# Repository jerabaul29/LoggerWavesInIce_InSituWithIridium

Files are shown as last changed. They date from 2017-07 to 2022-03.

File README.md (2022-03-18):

### NOTE - the content of this repository is kept available for archive, but we have a better instrument design released in 2021, see: https://github.com/jerabaul29/OpenMetBuoy-v2021a .

# Logger waves in ice with solar panel and Iridium communications

This is the repository for the 'waves in ice' instrument developed in this work:

```
An open source, versatile, affordable waves in ice instrument for scientific measurements in the Polar Regions
Jean Rabault, Graig Sutherland, Olav Gundersen, Atle Jensen, Aleksey Marchenko, Øyvind Breivik
```

https://www.sciencedirect.com/science/article/pii/S0165232X19300230

(preprint available here: https://arxiv.org/pdf/1901.02410.pdf ).

## Content of the repository

- **PCB_electronics**: details about the electronics boards.
- **DevelopmentCode**: code for the different components of the loggers.
- **ElectronicsList**: some bookkeeping of which components I need to buy to assemble. May be outdated.
- **SeedOPL**: the Seeed studios standard library. Could be used for putting the components on PCB from factory, not used now.

Quite a lot of cleaning and more detailed readmes is needed. This will happen as time goes and new series of instruments get built. If you have any questions, open an issue and / or feel free to contact me at ```jean.rblt@gmail.com```.

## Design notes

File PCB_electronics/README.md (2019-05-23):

PCB files. The software used for developing this is the Open Source KiCAD.

Most advanced PCB is in **Logger_and_power_v1**.

Production was made through Seeed.

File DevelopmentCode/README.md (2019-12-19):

# DevelopmentCode

Development code for all the modules of the logger, including processing on the Pi.

Each folder contains one component.

The Arduino stuff was developped in Visual Studio Code with the PlatformIO IDE; this may explain for some specificities in the folder structures.

- **ArduinoMega**: the code on the Arduino Mega on the center PCB; effectively, the logger and interface to all other components.

- **PowerControl**: the power controller, ie controlling the solar panel, battery, and wakeup planning.

- **RPI_side**: the stuff on the RPI. An image of the RPi image ready for use is available here: https://folk.uio.no/jeanra/Research/img_0208_Rpi_2Bv11.img .

- The rest is tests, help, etc.

# Old ------------

## To build a logger:

- upload the power controller and put it on the PCB.

Note: check the values in the parameters.h. In particular for production (no debugs or similar, and update the solar panel each 40s, possibility for main
instrument wakeup each 20 minutes):

- DEBUG should be false
- SHOW_LED should be false
- CYCLES\_DEEP\_SLEEP should be 5
- CYCLES\_BEFORE\_MEGA\_WAKEUP should be 30

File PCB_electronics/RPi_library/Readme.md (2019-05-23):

The RPi files are from here:

https://github.com/joeferner/kicad-library/tree/master/libs

The files here are just copies of the content of the repo.

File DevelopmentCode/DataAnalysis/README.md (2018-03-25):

# some code to help looking at the data obtained by the logger

## Setup

- set up a google account for iridium data (if necessary, forward from main account: wheel -> settings -> *filters and blocked addresses* then *forwarding and pop / imap* )
- set up the google account for allowing POP messaging: wheel -> settings -> *forwarding and pop / imap* : enable POP
- set up the google account to accept 'unsafe' applications: wheel -> settings -> *accounts and imports* -> other google account settings -> apps with account access -> allow less secure apps: on
- create a local clone of the repository containing the data (example https://github.uio.no/jeanra/LoggerWaveIceSolarIridiumRaspberry )

## Use of the code

- check if some new data has been received: *python run_interaction_with_gmail.py* . This will download through POP the data received on the gmail account, add it to the local repo, and push. Always use data from the local repo, as data is only obtained once through POP.
- do some plots (NOTE: will need to adapt the parameters of the script, in particular date intervals for plotting): *python run_process_data.py* .

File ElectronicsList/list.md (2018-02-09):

A list of what is needed in terms of electronics:

--------------------------------------------------------------------------------
- v prototype 09 02 2018:

- power manager:
05 -- 1 x ATMega 328P                                       Adafruit
20 -- 2 x IRLB8721                                          Adafruit / Elfa
10 -- 1 x (16 Mhz crystal + 2 capacitors)                   Adafruit
Ol -- 1 x 220 Ohm                                           Elfa
Ol -- 5 x 56 k Ohm                                          Elfa
Ol -- 1 x 39 k Ohm                                          Elfa

- caps
Ol -- 3 x supercap 2.5V 60F                                 Elfa
Ol -- 3 x 30 k Ohm                                          Elfa
Ol -- 1 x cap 40V 1000 micro F                              Elfa
Ol -- 1 x cap 1 micro F                                     Elfa

- step up converter
10 -- 1 x Pololu 5V Step-Up Voltage Regulator U3V50F5       Pololu

- Iridium
3 -- 1 x RockBlock 7                                       RockBlock7
2 + 2 -- 1 x antenna (weather hardened?)                       RockBlock7

- Arduino Mega:
Ol -- 1 x Arduino Mega                                      Elfa
Ol -- 1 x (MAX3323EEPE+ + 4 x 0.1 micro F caps)             Elfa
05 -- 1 x GPS breakout                                      Adafruit
05 -- 1 x GPS antenna                                       Adafruit
05 -- 1 x GPS antenna adapter                               Adafruit
05 -- 1 x SD card reader breakout                           Adafruit
05 -- 1 x SD card                                           Adafruit / Elfa
OK -- 1 x IRF5210                                           Adafruit / Elfa
Ol -- 2 x 46 k Ohm                                          Elfa

- Raspberry Pi:
OK -- 1 x zero or B+ or 2                                   Adafruit / Elfa
-- 1 x micro USB                                         Elfa
-- 1 x (micro USB  -- OR -- USB) to square USB           Elfa

- solar panel:
OK -- 3 x (medium 2W solar panels)                          Adafruit

- to add:
see Olav -- water tight boxe for antenna                          Adafruite / Elfa
see Olav -- pelican cases
OK -- battery cells LiFePO4

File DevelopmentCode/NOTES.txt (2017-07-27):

NOTES

- power control system: give access to all Arduino pins in PCB CAD (using headers).

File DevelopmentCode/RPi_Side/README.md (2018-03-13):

# RPi_side

This folder contains the code to be put on the Raspberry Pi of the logger.

## Present folder structure and files

The following folders and files should be present on the RPi in **/home/pi/Logger/**:

.
├── Code
│   ├── launch_processing_RPI.py
│   ├── RPi_Control.py
│   ├── script_RPi.sh
├── Commands
├── Data
├── filename_list.txt
├── Logs
├── README.md
└── ResultAnalyzis

The following should be added to the sudo crontab (sudo crontab -e):

```
@reboot bash /home/pi/Logger/Code/script_RPi.sh
```

## Setup of the RPi

- Get a copy of Raspbian lite: https://www.raspberrypi.org/downloads/raspbian/
- Use *startup disk creator* to create the SD card with Raspbian
- Make the system able to boot on ssh: add an empty 'ssh' file in the boot partition of the SD card
- Disable internet on main computer
- Connect RPi and computer with ethernet
- Give current to RPi to boot RPi
- Find the IP of the host computer: *hostname -I* Example output: 10.42.0.1
- Find the IP of the RPi: *nmap -sP IP__.\** Example: *nmap -sP 10.42.0.\**
- Connect to the RPi: ssh pi@IP_RPi
- There may be a warning because of SSH fingerprint; follow instructions to ignore
- Default RPi password: raspberry
- Change password on the RPi using the *passwd* command, for example to: user: pi password: 55732gg88j
- Enable internet on main computer to share connection to RPi
- Update RPI: *sudo apt-get update* and *sudo apt-get upgrade*
- Install some base packages: *sudo apt-get install vim* and *sudo apt-get install python-pip* 
- Install pip, and necessary packages: *sudo pip install pyserial*, *sudo pip install printind*, *sudo pip install crcmod* **NOTE**: use *apt-get* instead to not need to compile the heavy packages. example: *sudo apt-get install python-numpy* and *sudo apt-get install python-matplotlib* and *sudo apt-get install python-scipy* .
- Copy the logger files to the RPi and setup the tree structure: go to *example_structure_on_Pi* and *scp -r * pi@IP_Pi:/home/pi/*
- Copy the code to the Code folder: *scp *.py pi@IP_Pi:/home/pi/Logger/Code/* and *scp *.sh pi@IP_Pi:/home/pi/Logger/Code/*
- change the parameters in the logger code: in **launch_processing_debugging.py** use *main_path=/home/pi/Logger* , if necessary make the *debug=True* or *False*. Debug indicates if use the true data or the dummy data for testing the processing code. path is dependent on my laptop vs RPi. verbosity is controlled by the verbose parameter.
- Run tests to check that everything ok.
- Once the system is working and communicating with the logger, reduce boot time following https://folk.uio.no/jeanra/Informatics/GettingStartedRaspberryPi.html : *sudo update-rc.d networking remove* *sudo update-rc.d dhcpcd remove* *sudo systemctl disable dphys-swapfile*
- Prepare the script (*chmod +x script_RPi.sh*) and set up the crontab for automatically starting processing and then shutting off: *sudo crontab -e* and then add the script: *@reboot sh /home/pi/Logger/Code/script_RPi.sh* .
- Do last test with RPi reduced booting time.

## Reminders

Some reminders from https://folk.uio.no/jeanra/Informatics/GettingStartedRaspberryPi.html

### Access to RPi

To be able to talk to the RPi by ssh make sure that:

- Network is available (if necessary crontab) and ssh is openend
- The Pi does not shutoff immediately; for this, may be necessary to plug a dummy
Arduino
- In order to upload code to the RPi, from this folder do: ```scp * pi@10.42.0.214:/home/pi/Logger/Code/.```
- If necessary, see the webpage on my website: https://folk.uio.no/jeanra/Informatics/GettingStartedRaspberryPi.html

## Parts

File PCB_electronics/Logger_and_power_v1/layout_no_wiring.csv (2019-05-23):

Id | Designator | Package | Quantity | Designation | Supplier and ref
1 | C1,C2 | C_Disc_D3_P2.5 | 2 | 20pF
2 | C3 | C_Radial_D8_L11.5_P3.5 | 1 | 1uF
3 | C4,C5,C6,C7 | C_Disc_D3_P2.5 | 4 | 1.0uF
4 | C8 | C_Radial_D8_L13_P3.8 | 1 | 1000uF
5 | D1 | LED-3MM | 1 | LED
6 | IC1 | DIP-28_W7.62mm_LongPads | 1 | ATMEGA328-P
7 | P1 | WireConnection_2.00mmDrill | 1 | SOLAR_PANEL
8 | P2 | WireConnection_2.00mmDrill | 1 | 5V_pololu
9 | P3 | WireConnection_2.00mmDrill | 1 | BATT
10 | P4 | WireConnection_2.00mmDrill | 1 | SUPERCAPS
11 | P5 | Pin_Header_Straight_1x09 | 1 | GPS_breakout_connector
12 | P6 | Pin_Header_Straight_1x08 | 1 | SD_breakout_connector
13 | P7 | Pin_Header_Straight_1x05 | 1 | Iridium_connector
14 | P8 | Pin_Header_Straight_1x04 | 1 | VN100_connector
15 | P9 | Pin_Header_Straight_2x01 | 1 | RPI_connector
16 | P10,P11 | Pin_Header_Straight_1x08 | 2 | CONN_01X08
17 | P12 | Pin_Header_Straight_1x03 | 1 | CONN_01X03
18 | P13,P14,P15 | Pin_Header_Straight_2x01 | 3 | CONN_01X02
19 | R1 | Resistor_Horizontal_RM10mm | 1 | 5.6k
20 | R2 | Resistor_Horizontal_RM10mm | 1 | 3.9k
21 | R3,R5,R6,R7 | Resistor_Horizontal_RM10mm | 4 | 50k
22 | R4 | Resistor_Horizontal_RM10mm | 1 | 220
23 | R8 | Resistor_Horizontal_RM10mm | 1 | 46k
24 | R9 | Resistor_Horizontal_RM10mm | 1 | 32k
25 | U1 | TO-220_Neutral123_Vertical | 1 | IRLB_8721_SOL
26 | U2 | TO-220_Neutral123_Vertical | 1 | IRLS-8721_MEGA
27 | U3 | DIP-16_W7.62mm_LongPads | 1 | MAX232
28 | U4 | TO-220_Neutral123_Vertical | 1 | FQP27P06
29 | XA1 | Arduino_Mega2560_Shield | 1 | Arduino_Mega2560_Shield
30 | Y1 | Crystal_HC49-U_Vertical | 1 | 16MHz
31 | W1 | NetTie-I_Connected | 1 | NET-TIE

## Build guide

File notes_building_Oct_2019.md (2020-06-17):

# build the PCB 'as usual'. Fixes:

- 3.9k -> 39k
- 5.6k -> 56k
- 1.0 uF -> 0.1 uF
- 32k, 46k, 50k -> 47k

# programming procedure

NOTE: all the following is tested on Ubuntu.

## code for the Arduino barebone

- power controller: using commit **b76f6a5** (current master IS BROKEN), upload the code in the **PowerControl** folder on the barebone Arduino (for example, using an Arduino Uno to program the chip). Check the **parameters** and that you are ready for deployment, not test. This can be done either by using ```git checkout``` or by using the folder in **DevelopmentCode/PowerController_commitb76f6a5**.

- go back to master in the code

## code for the Arduino Mega logger

- take away the Arduino from logger shield

- Initialize the EEPROM (run **InitializeEEPROM** on the Mega).

- upload the code (from **ArduinoMega**, current master, for example using commit **39c30775849a**). Make sure that you well use the extended buffer compilation flags (see the platformio.ini parameters folder). The sizes of the data and program should read something in this kind:

```
DATA:    [========  ]  81.5% (used 6673 bytes from 8192 bytes)
PROGRAM: [=         ]  10.9% (used 27732 bytes from 253952 bytes)
```

I use the platformio plugin on Visual Studio Code to compile / upload.

## VN100 setup

The VN100 needs to be setup similarly to the waves in ice logger in binary configuration:

https://github.com/jerabaul29/LoggerWavesInIce/tree/master/Logger_GPS_SD_VN_Binary_output

```
---------------------------------------------------------------
The configuration of the VN100 is:

Baud rate      : 57600
Async          : NoOutput
Binary output 1: 
    Async mode    : Serial Port 1
    Rate dividor  : 80
    Common group  : None
    IMU group     : UncompensatedMag
                    UncompensatedAccel
                    UncompensatedGyro
                    Temp
                    Press
    Attitude group: Yaw Pitch Roll
                    DCM
                    MagNed
                    AccelNed
    IMU filtering : 80
 
 This corresponds to the binary header (in HEX):
 fa 14 3e 00 3a 00
 
 The length of the message is (in byte): 123
 
 Note that the post can have in addition an
 end of line marker (in HEX):
 0a 0d
 ---------------------------------------------------------------
 
 ---------------------------------------------------------------
 To examine the content of the SD card on Linux computer,
 use for example xxd:
 
 tail -x FileName | head -y | xxd
 ---------------------------------------------------------------
 
 ---------------------------------------------------------------
 CAUTION: when using VectorNav software, do not forget to:
 - connect to the sensor
 - write to non volatile memory (right click on the sensor in the tree view)
 - disconnect from the sensor
 ---------------------------------------------------------------
 ```

# Raspberry Pi

NOTE: use RPi Pi 2 Model B v1.2, NOT RPi Pi model B+ v1.2.

This is to setup the RPi SD card.

Can either use the code in the DevelopmentCode / RPi_Side and the tips on my website post: https://folk.uio.no/jeanra/Informatics/GettingStartedRaspberryPi.html .

or

Use the Raspberry Pi image (for example, tested and verified with **img_0208_Rpi_2Bv11.img**). Then:

TODO: find the image from the HDD and upload.

- Format SD card (exFAT)

- Find it the name of the SD card: ```sudo fdisk -l```

- Unmount it (for example, if /dev/mmcblk0 is the SD card): ```sudo umount /dev/mmcblk0```

- Copy the right image using dd. Be careful, this is a 'dangerous' command.

1. note: this works:
    ```sudo dd if=/media/jrlab/SAMSUNG/Images_RPi/img_0208_Rpi_2Bv11.img dd of=/dev/mmcblk0 bs=4M```

2. note: seems that this works
    ```sudo dd if=/media/jrlab/SAMSUNG/Images_RPi/img_0208_Rpi_2Bv11.img | pv | sudo dd of=/dev/mmcblk0 bs=4M```

3. note: seems to work and be relatively fast
    ```sudo dd if=/media/jrlab/SAMSUNG/Images_RPi/img_0208_Rpi_2Bv11.img bs=16M | pv | sudo dd of=/dev/mmcblk0 bs=16M```

- If using a larger SD card than the image size (16GB), for example a 32GB card, resize the root partition to full size:

### method 1 for resizing

1. look with gparted at the right device (for example, /dev/mmcblk0).

2. if necessary, unmount partitions.

3. use resize to grow the root partition (for example, /dev/mmcblk0p2)

### method 2 for resizing

From https://raspberrypi.stackexchange.com/questions/499/how-can-i-resize-my-root-partition .

From the command line or a terminal window enter the following

sudo fdisk /dev/mmcblk0

then type p to list the partition table

you should see three partitions. if you look in the last column labeled System you should have

    W95 FAT32
    Linux
    Linux Swap

make a note of the start number for partiton 2, you will need this later. though it will likely still be on the screen (just in case).

next type d to delete a partition.

You will then be prompted for the number of the partition you want to delete. In the case above you want to delete both the Linux and Linux swap partitions.

So type 2

then type d again and then type 3 to delete the swap partition.

Now you can resize the main partition.

type n to create a new partition.

This new partition needs to be a primary partition so type p.

Next enter 2 when prompted for a partition number.

You will now be prompted for the first sector for the new partition. Enter the start number from the earlier step (the Linux partition)

Next you will be prompted for the last sector you can just hit enter to accept the default which will utilize the remaining disk space.

Type w to save the changes you have made.

Next reboot the system with the following command:

sudo reboot

once the system has reboot and you are back at the commandline enter the following command:

sudo resize2fs /dev/mmcblk0p2

Note: this can take a long time (depending on the card size and speed) be patient and let it finish so you do not mess up the file system and have to start from scratch.

Once it is done reboot the system with the following command:

sudo reboot

You can now verify that the system is using the full capacity of the SD Card by entering the following command:

df -h

### For example, working fine with:

```
(VE_P2) jrlab@jrlab-T150s:~$ sudo fdisk /dev/mmcblk0
[sudo] password for jrlab: 

Welcome to fdisk (util-linux 2.27.1).
Changes will remain in memory only, until you decide to write them.
Be careful before using the write command.

Command (m for help): p
Disk /dev/mmcblk0: 29,7 GiB, 31914983424 bytes, 62333952 sectors
Units: sectors of 1 * 512 = 512 bytes
Sector size (logical/physical): 512 bytes / 512 bytes
I/O size (minimum/optimal): 512 bytes / 512 bytes
Disklabel type: dos
Disk identifier: 0x823a85f9

Device         Boot Start      End  Sectors  Size Id Type
/dev/mmcblk0p1       8192    93236    85045 41,5M  c W95 FAT32 (LBA)
/dev/mmcblk0p2      94208 31116287 31022080 14,8G 83 Linux

Command (m for help): 

Command (m for help): d
Partition number (1,2, default 2): 2

Partition 2 has been deleted.

Command (m for help): n
Partition type
   p   primary (1 primary, 0 extended, 3 free)
   e   extended (container for logical partitions)
Select (default p): p
Partition number (2-4, default 2): 2
First sector (2048-62333951, default 2048): 94208
Last sector, +sectors or +size{K,M,G,T,P} (94208-62333951, default 62333951): 

Created a new partition 2 of type 'Linux' and of size 29,7 GiB.

Command (m for help): w
The partition table has been altered.
Calling ioctl() to re-read partition table.
Syncing disks.

(VE_P2) jrlab@jrlab-T150s:~$ sudo e2fsck -f /dev/mmcblk0p2
e2fsck 1.42.13 (17-May-2015)
Pass 1: Checking inodes, blocks, and sizes
Pass 2: Checking directory structure
Pass 3: Checking directory connectivity
Pass 4: Checking reference counts
Pass 5: Checking group summary information
rootfs: 55411/940576 files (0.2% non-contiguous), 447272/3877760 blocks
(VE_P2) jrlab@jrlab-T150s:~$ sudo resize2fs /dev/mmcblk0p2
resize2fs 1.42.13 (17-May-2015)
Resizing the filesystem on /dev/mmcblk0p2 to 7779968 (4k) blocks.
The filesystem on /dev/mmcblk0p2 is now 7779968 (4k) blocks long.

```

# Buying Iridium credits

- Go to https://rockblock.rock7.com

- Buy the amount of credits and line rental you want.

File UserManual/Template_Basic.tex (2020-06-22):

\documentclass[pdftex,a4paper,12pt,twocolumn,fleqn,captions=tableheading]{scrartcl}

\usepackage[british]{babel}
\usepackage[utf8]{inputenc}
\usepackage[T1]{fontenc}
\usepackage{graphicx}
\usepackage{booktabs}
\usepackage{caption}
\usepackage{subcaption}
\usepackage{lmodern}
\usepackage{microtype}
\usepackage{textcomp}
\usepackage{amssymb}
\usepackage{epstopdf}
\usepackage{capt-of}
\usepackage{amsmath}
\usepackage{float}
\usepackage{xfrac}
\usepackage{dblfloatfix}
\usepackage{url}
\usepackage[squaren,Gray]{SIunits}
\usepackage{commath}
\usepackage{listings}
% \usepackage{siunitx}

\addtokomafont{caption}{\small}
\setkomafont{captionlabel}{\sffamily\bfseries}

\usepackage[nottoc]{tocbibind}

% page layout
\usepackage[a4paper,onecolumn]{geometry}
\geometry{hmargin=60pt,top=60pt,bottom=80pt}
% \geometry{onecolumn,columnsep=20pt}
\geometry{head=10pt,headsep=20pt,foot=35pt}

% header and footer
\usepackage{fancyhdr}
\setlength{\headheight}{15pt}
\pagestyle{fancy}
%\fancyheadoffset{9pt}
%\fancyfootoffset{9pt}
\lhead{}	\chead{User manual IMU instruments with Iridium communications}	\rhead{}
\lfoot{}	\cfoot{J. Rabault \\ \thepage}	\rfoot{}
%\renewcommand{\headrulewidth}{0,1 mm}
\renewcommand{\footrulewidth}{\headrulewidth}

\begin{document}
% top matter
\title{Using the waves in ice IMU instruments with Iridium communications}
\author{J. Rabault
  }
\date{\today}

\maketitle

This is a short user manual for the IMU waves in ice instruments with Iridium communications. In all the following, I describe how the instruments are set up after assembly at UiO, but it should be roughly the same also if they are built in-house by another group. For more details about the instrument, see the detailed paper (Rabault et. al., Cold Region Science and Technology (2020), "An Open Source, Versatile, Affordable Waves in Ice Instrument for Remote Sensing in the Polar Regions"), available as a preprint at: ~\\

\url{https://www.researchgate.net/publication/330241626_An_Open_Source_Versatile_Affordable_Waves_in_Ice_Instrument_for_Remote_Sensing_in_the_Polar_Regions}.

\section{Introduction}

The instrument has a few main components:

\begin{itemize}
  \item Master PCB, including voltage regulator, SD card, GPS connected to its antenna, and some various small components, which are set up on top of an Arduino Mega.
  \item Iridium moden connected to its antenna.
  \item Raspberry Pi microcomputer.
  \item Solar panel and battery.
  \item Inertial Motion Unit (IMU, possibly hidden at the bottom of the box depending on the assembly).
\end{itemize}

All the components are visible on the figures \ref{FromOutside} and \ref{FromInside}.

  \begin{figure}
  \begin{center}
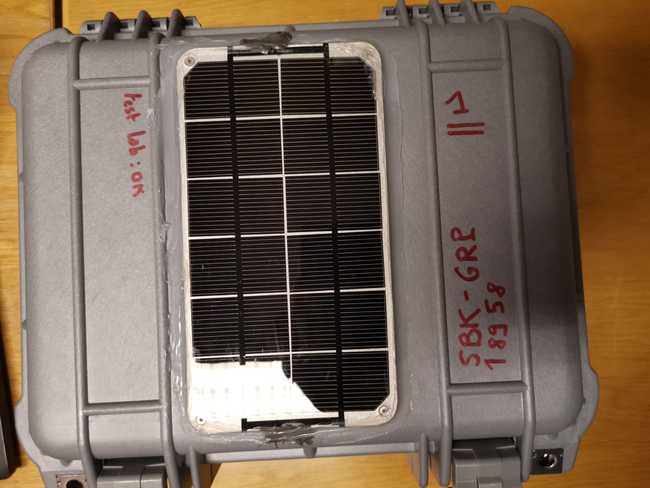
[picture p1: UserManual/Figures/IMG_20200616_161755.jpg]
  
  \caption{\label{FromOutside} The instrument seen from the top, with solar panel, and a written copy of the Iridium modem reference number (here, SBK-GRP 18958). In addition, each instrument in a production series is given a number, here this is instrument number 1.}
  \end{center}
  \end{figure}

  \begin{figure}
  \begin{center}
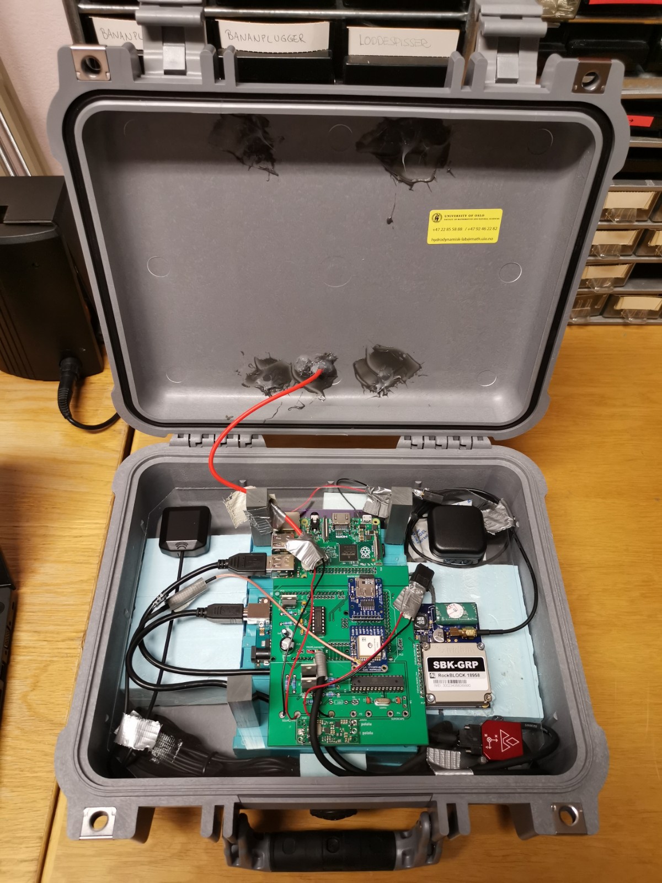
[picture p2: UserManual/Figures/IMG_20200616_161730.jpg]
  
  \caption{\label{FromInside} The instrument seen inside. The different components are clearly visible: IMU (red component at the lower right), GPS antenna (upper left), Iridium antenna (upper right), main PCB on top of an Arduino Mega including SD card reader, GPS module, and small electronics, Iridium model (right), RaspberryPi microcontroller (top), USB cable linking Raspberry Pi and Arduino Mega, single cell battery at the bottom.}
  \end{center}
  \end{figure}

\section{Use}

Any instrument shipped has been fully tested at UiO and should work "out of the box". Instruments being shipped are powered off, and the only step necessary before use is to switch on the instruments (see following). In addition, you need to notify me (address: jean.rblt@gmail.com) before deployment so that I can start Iridium subscriptions for data transmission. If you want to receive a forwarding of the iridium data, send an additional email to the same address. ~\\

To deploy:

\begin{itemize}
  \item Open the instrument. Remember that electronics are very sensitive to static electricity discharges / sparks, so try to touch the PCBs / electronics as little as possible, and try to "discharge yourself" by touching a large metallic mass before opening the instrument. Try to only open the instrument either inside a vehicle, or outside when the conditions are good, so that no snow / water is introduced. Some desiccant bags are hidden at the bottom of the instrument, so it should be fairly resistant to a bit of humidity.
  \item Take a short visual inspection to make sure that the instrument was not damaged during transport: check visually that all cables are in place, and nothing looks broken (SD card inserted, USB cable in place, GPS antenna cable in place).
  \item Find the main power connectors. These should be the only 2 loose connectors present in the box. They may be taped inside the box to make sure that they do not "move around" during transport.
  \item Connect the 2 main power connectors. Make sure that you engage them fully all the way.
  \item At this stage, the GPS LED should start blinking. Depending on the number of sleep cycles left, either it will only blink for a few seconds before turning off (which means that the instrument goes into sleep mode until it should perform a measurement, this is normal), or it will continue blinking, and the SD card reader will start blinking too, in which case a measurement is starting (this is also normal behavior). If nothing blinks, you may consider the "troubleshooting" section. Note that the blinking may be quite low intensity and hard to see, especially outdoors.
  \item At this stage, the instrument is ready: close it and put it on the ice. Make sure that you do not pinch any cables when closing the top lid.
\end{itemize}

  \begin{figure}
  \begin{center}
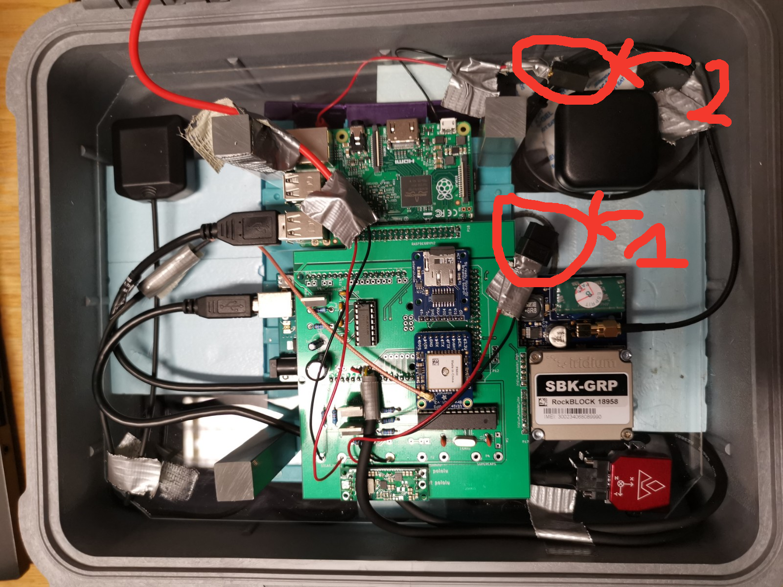
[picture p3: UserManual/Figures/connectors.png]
  
  \caption{\label{Connector} The main power connectors are highlighted in red. Connect them fully and securely, and the instrument will start. Depending on the exact instrument, either the connector shown, or a slightly different connector model, may be used. Feel free to rip off the tape holding the connectors, this is only used to secure everything during transport. The connectors can only be inserted in the right polarisation direction.}
  \end{center}
  \end{figure}

Once this is done, the instrument will periodically transmit through Iridium its position and the wave information. The typical wake-up cycle is: 2.5 hours sleep, 0.5 hours logging, and sending of a message. ~\\

A few points about the instruments deployment:

\begin{itemize}
  \item Place the instrument directly on the ice. If there is a small layer of snow (up to half the height of the box), take away the snow, and put the instrument directly on the ice. Feel free to pack a bit of snow on all 4 sides of the instrument, to stabilize it, without covering it.
  \item The antenna immediately under the lid need a good vision of the sky in order to perform well, so it is important to try to deploy the instrument in a place where it is not too likely to get buried under snow.
  \item The box is water-proof and has buoyancy, however it does not float very well, especially without the addition of an external floater.
\end{itemize}

Try to not start / stop the instruments: just let them on for the full duration of the deployment if no problem is encountered. Do not try to disconnect any cables / remove SD cards or other. All relevant data are transmitted through Iridium anyways. If necessary, to stop the instruments:

\begin{itemize}
  \item Cover the solar panel with a dark, mate, opaque cover, and keep it covered the whole time of the procedure. If not, the solar panel will continue providing enough energy to keep the instrument on.
  \item Disconnect the main power connector. Secure both ends with a bit of tape.
  \item To make sure that all capacitors are emptied, and that all electronics is shut off rather than in compromised browned-out mode, use the provided cable to short the 2 "supercaps" pads, as visible in Fig. \ref{shorting}. Make sure that you perform the shorting AFTER the main power connector has been disconnected, otherwise, you are attempting to short the battery.
\end{itemize}

  \begin{figure}
  \begin{center}
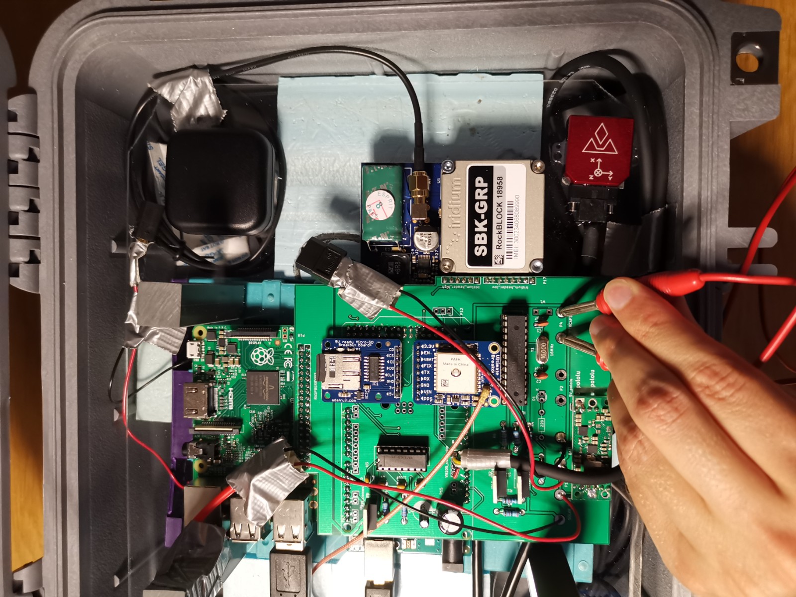
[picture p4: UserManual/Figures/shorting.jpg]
  
  \caption{\label{shorting} shorting of the "supercaps" pins using the provided cable, in order to empty all capacitors and make sure that the electronics is not let in a browned-out state.}
  \end{center}
  \end{figure}

\section{Extraction of raw data}

\textbf{Warning: make sure to be very careful when extracting / inserting SD cards on the main PCB}.

Data of interest (i.e., GPS position, significant wave height, peak period, binned spectra) are transmitted through Iridium. However, the Iridium data do not include the full raw signal.

In order to extract the raw wave data:

\begin{itemize}
  \item Extract the SD card visible on the main PCB. This is a press in / press out mechanism: press and release to eject.
  \item Copy all files on the SD card back to your computer. Do not change anything to the formatting of the SD card or the files contained.
  \item Insert back the SD cad: press and release to insert.
\end{itemize}

I would advise to perform this operation when the logger is sleeping and not active (i.e., no blinking LEDs on the SD and GPS shields), and to not switch on / off the logger for performing this operation. It should take only a few seconds to copy the data, and the probability that the logger wakes up then is quite little. \\~\\

If you perform data extraction from several instruments, \textbf{make sure that each instrument gets back its initial SD card}, i.e. \textbf{do not permutate SD cards between instruments}.

\section{Troubleshooting}

The design has been tested and operated without problems in several campaigns, both in the Arctic and the Antarctic.

The main possible sources of troubles include: 1) the instruments being covered by snow 2) the instruments being destroyed by polar bears 3) the instruments falling in the water / being crushed following ice breakup. If possible, try to mitigate these hazards by choosing a relevant deployment location. These are conflicting trade-offs (for example, for polar bear resistance we chose to design the instruments to have a low profile and no mast, while this also means that the instruments are more likely to get covered by snow).

The instruments should have enough power through the solar panel to sustain continuous operation with around 8 to 10 hours of sun per day. The batteries included should allow operation without any solar input for at least 1 to 2 months depending on the frequency of data transmission.

The only issue encountered so far in deployments was failure to start up due to browned-out state of the electronics. This can happen if the instruments are switched off but not shorted, and / or (note: uncertain) if the instruments are let in the sun before turning on, in which case they may be started by the solar panel alone even without power from the battery.

To reset the instrument and start them in this case, 1) disconnect the main connector, 2) cover the solar panel with something opaque, 3) short the supercaps pads with the provided cable, 4) start the instruments by connecting the main connector.

If other issues occur, or you encounter any problem using or deploying the instruments: take contact with Jean Rabault: jean.rblt@gmail.com.

\end{document}

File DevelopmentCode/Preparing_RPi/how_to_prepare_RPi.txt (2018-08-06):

- possibility 1: if there is already the right iso image for the kind of RPi that is being used:

-- insert SD card
-- re-format
-- find it:
    sudo fdisk -l
-- unmount it (for example, if /dev/mmcblk0 is the SD card):
    sudo umount /dev/mmcblk0
-- copy the right image
note: this works:
    sudo dd if=/media/jrlab/SAMSUNG/Images_RPi/img_0208_Rpi_2Bv11.img dd of=/dev/mmcblk0 bs=4M
note: seems that this works
    sudo dd if=/media/jrlab/SAMSUNG/Images_RPi/img_0208_Rpi_2Bv11.img | pv | sudo dd of=/dev/mmcblk0 bs=4M
note: seems to work and be relatively fast
    sudo dd if=/media/jrlab/SAMSUNG/Images_RPi/img_0208_Rpi_2Bv11.img bs=16M | pv | sudo dd of=/dev/mmcblk0 bs=16M
    
--------------------------------------------------------------------------------
- possibility 2: if no right image for the kind of RPi yet:

-- format SD card
-- Download Raspbian version lite
-- create a SD bootable card using startup disk creator
-- use the RPi with a screen and english keyboard etc to do the setup
-- change password
-- sudo apt-get update
-- sudo apt-get upgrade

-- sudo apt-get install vim
-- sudo apt-get install python-pip

// NOTE: DO NOT use pip, too slow:

// -- sudo pip --no-cache-dir install numpy printind scipy matplotlib binascii fnmatch crcmod pyserial

use sudo:

sudo apt-get install python-numpy python-scipy python-matplotlib
sudo pip --no-cache-dir install printind crcmod pyserial

-- set the crontab:
    crontab -e
and then add:
    @reboot sh /home/pi/Logger/Code/script_RPi.sh
(note: located at rootfs/var/spool/cron/crontabs)

once seems to work:

apply the booting time optimization (suppress output, suppress network, etc)
that are described here:

https://folk.uio.no/jeanra/Informatics/GettingStartedRaspberryPi.html

NOTE: on the RPI 1 B, seems need a reboot to see the Arduino

--------------------------------------------------------------------------------
change password
azerty5+@RPi)

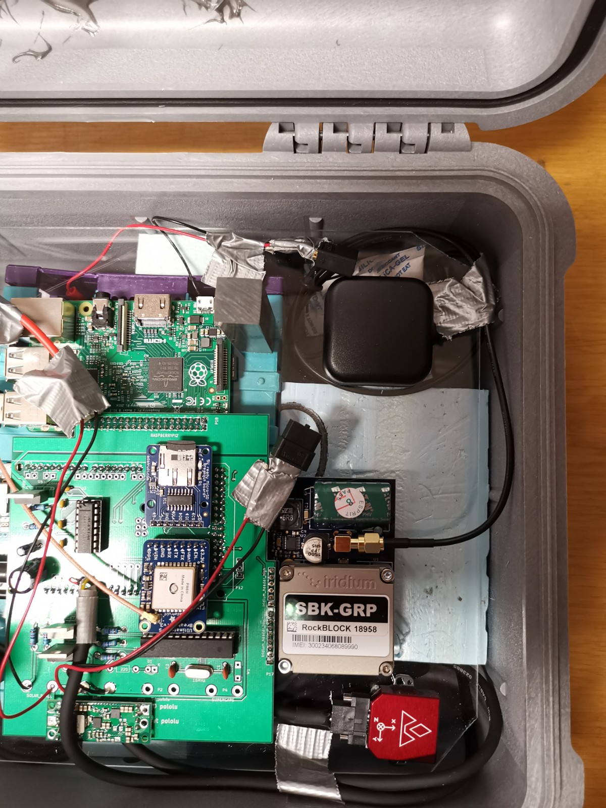
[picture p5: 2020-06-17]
UserManual/Figures/IMG_20200616_161638.jpg

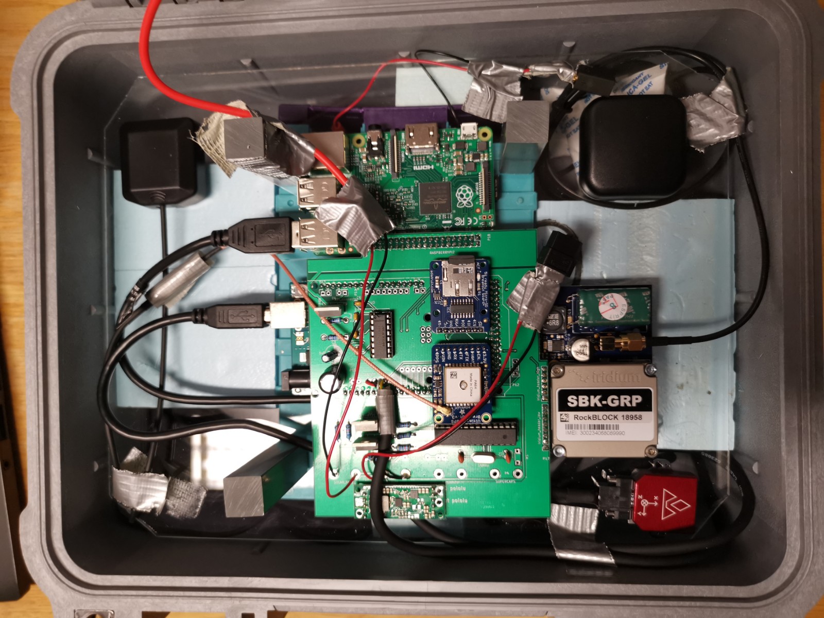
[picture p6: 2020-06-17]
UserManual/Figures/IMG_20200616_161747.jpg

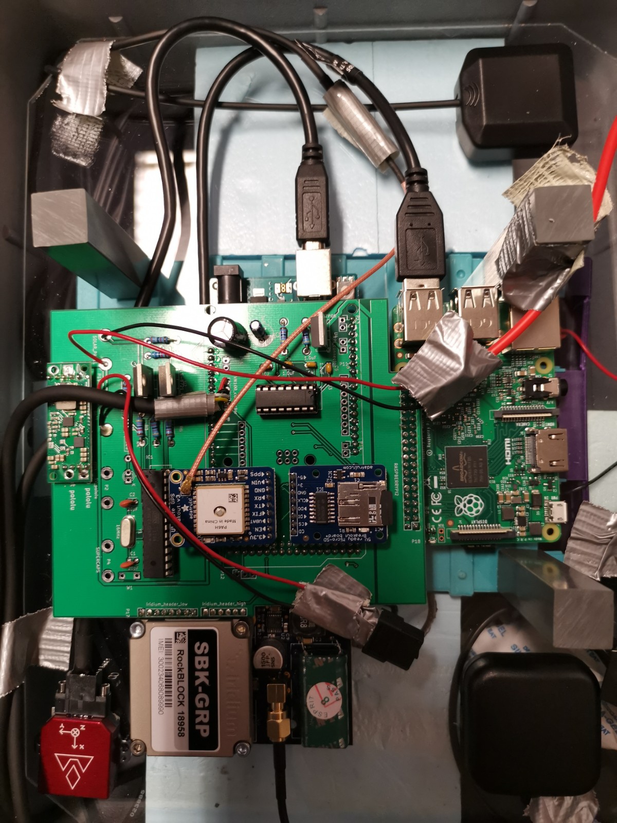
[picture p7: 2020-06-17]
UserManual/Figures/IMG_20200616_161645.jpg

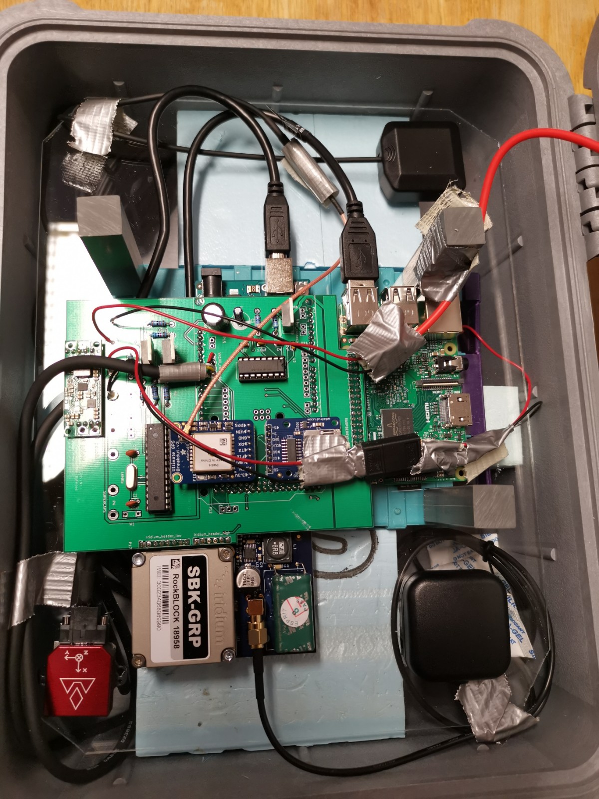
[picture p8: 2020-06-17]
UserManual/Figures/IMG_20200616_161555.jpg

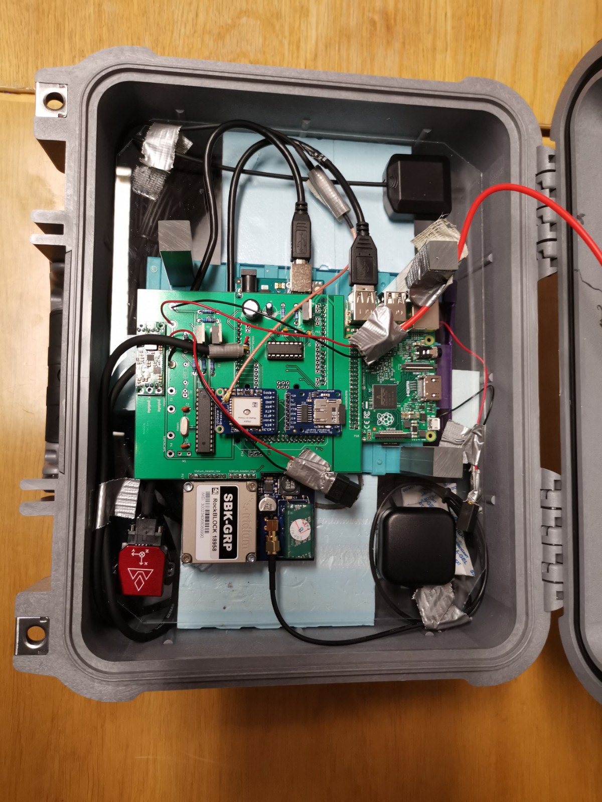
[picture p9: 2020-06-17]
UserManual/Figures/IMG_20200616_161649.jpg

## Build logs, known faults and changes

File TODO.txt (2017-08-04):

- add a 'finished gracefully' stamp in the RaspberryPi folder structure
- try with the other Pi models (less power consumption)
- processing on the Pi
- sending back information from the Pi

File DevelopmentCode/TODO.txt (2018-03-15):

- Electronics CAD:
Do the electronics drawings

- RPi side:
processing code
sending by Iridium

- Arduino side:
send the RPi data through Iridium
timeout on RPi processing to avoid complete hanging

- Power controller: go through code and make a website post

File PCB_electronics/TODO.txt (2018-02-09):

- see if can change to 3.3V everywhere to save power; in worst case, 3.3V / 5V mix
- add capacitors to the board (at least, solder points)
- add the Mega to the board (barebone Mega + include USB FTDI chip)
- add the power regulators to the board (need to buy from TI and deliver to seeed)

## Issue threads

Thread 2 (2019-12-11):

stop charging when full battery

jerabaul29, 2019-12-11:
@jvoermans I would think that these lines:

https://github.com/jerabaul29/LoggerWavesInIce_InSituWithIridium_private/blob/a2df4c4adb81192624e53e88bad405452b68f7e6/DevelopmentCode/PowerControl/solar_controller.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

should ensure that the solar panel does not overcharge the battery. If the voltage is over the max battery level set here:

https://github.com/jerabaul29/LoggerWavesInIce_InSituWithIridium_private/blob/a2df4c4adb81192624e53e88bad405452b68f7e6/DevelopmentCode/PowerControl/parameters.h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

then something very strange is happening.

I see for possibilities:

- 1 a bug in software somewhere.

- 2 a bug in hardware somewhere.

- 3 an overcharged battery before deployment: is it possible that the battery was wrongly charged / overcharged before being put inside the instrument? In this case, I would expect the voltage to be far too high 'since the beginning' of deployment, and it to fall progressively until the max voltage (3.6V), at which point it may either stay constant (if solar panel is strong enough to keep the battery full), or slowly decrease (if solar panel is not strong enough to keep fully charged).

I would be interested to hear if you can check if scenario 3 is corresponding to your results. If so, then it is not the problem of the logger, but how the battery was charged before deployment. If the battery starts at 3.6V, and only progressively while being deployed gets higher, then this indicates scenario 1 or 2 and I need to debug.

jerabaul29, 2020-08-20:
@jvoermans I have several instruments being deployed in the Arctic now, and the batteries are continuously close to fully charged but without overcharging. So it looks like the on / off switching of the solar panel works fine with these instruments....

There may be one explanation for this: are you using the exact same model of MOSFET in your instruments, or did you choose another model? There are many variations around these MOSFETs, and they have subtle differences. If you confirm that you went for another MOSFET model, if may be the explanation.

jvoermans, 2020-08-20:
I don't think the batteries were overcharged. The charger I supplied with the batteries should have overcharge protection.

I looked up the MOSFETs in my receipts, I got the following:
https://au.rs-online.com/web/p/mosfets/7259322/
https://au.rs-online.com/web/p/mosfets/6715064/

jerabaul29, 2020-08-20:
No worries :) . Yes, it looks like it was probably happening during deployment.

Mmh, ok, this looks like exactly the same components I used. Strange.

jvoermans, 2020-11-03:
@jerabaul29 As a follow-up on the above. I think there might be a bug in the code somewhere regarding battery reading.

Today, I just tested the 'added temperature sensor' sketch on an old logger. Battery is at 3.29V, first message said 4.60V, two hours later 4.59V and half hour after 2.98V.

Also, one of the two currently deployed in Antarctica has similar issue regarding battery voltage. It was around 2.5V whole time and still working. They brought it back to the station but battery was fully charged according to the station's electrician (3.5V). Deployed again and stays around 2.5V still working. Any ideas what to test?

jerabaul29, 2020-11-03:
Ok, many thanks for the update! This is strange, as I have never observed the problem myself with my instrument. Wonder if we use a different component somewhere without being aware about it. Or if we are operating in different regimes (maybe this bug appears only when the batteries are completely full and saturate, and this is not something I have observed myself). But then we know that we should just "safely ignore this information".

So it looks like an intermittent hardware / software issue. These can be really quite hard to debug, specially when I myself cannot reproduce the issue... I think it is best to just ignore this problem. Anyways we know the instruments work correctly in reality, which is great, and the most important. This will get better the day I do a full re-design of the instruments (trying to get a project about this, I will keep you posted and invite you to join the application if I am allowed to proceed by my boss :) ).

Closed 2021-11-06.

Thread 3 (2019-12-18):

Power Control

jvoermans, 2019-12-18:
Hi Jean,

Could you tell me how to upload the PowerControl code to the ATMega328P?
Do I just fix it to a Arduino Uno and upload?

Joey

jerabaul29, 2019-12-18:
Hi Joey,

Yes, exactly. The only things you need to be careful about is 1) do not discharge static electricity on the chip (ie touch metal before), 2) be careful to not bend the legs of the chip, 3) insert the chip in the right direction (i.e. check the position of the small circular mark).

Let me know if you have any problems.

Btw, is your instrument still working in the Antarctic? :)

jvoermans, 2019-12-18:
Ok, I did the following:

I directly put the ATMega328 on the Arduino Uno, uploaded the sketch. I put it on one of the spare loggers, but when connecting to power, it just keeps turning on every time I connect it, so I'm doing something wrong.

Should I do something like they do here?:
https://www.instructables.com/id/Build-your-own-Arduino-Bare-Bone-System/

FYI: the ship was still around the loggers, so they simply disconnected and reconnected the battery and it is transmitting again. The ice on which they are deployed is however protected from the Southern ocean by a second strip of ice, so there are basically now waves, but if the batteries are kept fully charged, we just have to wait and hope the ice floes don't melt ;)

jerabaul29, 2019-12-18:
Ok. Did you follow the instructions here?

https://github.com/jerabaul29/LoggerWavesInIce_InSituWithIridium/blob/master/notes_building_Oct_2019.md

"
code for the Arduino barebone
power controller: using commit b76f6a5 (current master IS BROKEN), upload the code in the PowerControl folder on the barebone Arduino (for example, using an Arduino Uno to program the chip). Check the parameters and that you are ready for deployment, not test.

go back to master in the code
"

Yes, this is the right technique. You can just use the Arduino IDE to compile, or platformio.

Ok. Do you mean there are 1 or 2 loggers active now? Is the logger that had a problem working again? Or still only 1 working?

jerabaul29, 2019-12-18:
So:

got checkout b76f6a5

Then upload

Then

git checkout master

You can check the status of the git tracking by 'gut status'. If you are confused I can create a separate folder with the code, may be easier to find, do it adap I have internet access to my computer.

jerabaul29, 2019-12-19:
@jvoermans if you are a bit less familiar with git commands you can just use the power controller code here:

https://github.com/jerabaul29/LoggerWavesInIce_InSituWithIridium/tree/master/DevelopmentCode/PowerControl_commitb76f6a5

Can you confirm to me that it works?

jvoermans, 2019-12-19:
Yes that worked! Thanks. That is one software problem down!

And yes, now both loggers are active again in the Antarctic! Not sure what the problem was, if reconnecting the battery solved it, that means that it is probably a hardware thing.

jerabaul29, 2019-12-19:
Mmmh, very strange, should not be able to happen. Maybe some bad contact of some sort between the battery and the logger that was solved by plugging in and out, or some bad soldering close to the plug that adjusted a bit with playing with the connector. Hope it holds. Good both work again :)

jerabaul29, 2019-12-19:
PS @jvoermans : make sure you adapt the wakeup parameters for wakeup frequency to your needs :)

https://github.com/jerabaul29/LoggerWavesInIce_InSituWithIridium/blob/6cec5acdfae4ed4b094409de874d25b971efb4b8/DevelopmentCode/PowerControl_commitb76f6a5/parameters.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

Closed 2019-12-19.

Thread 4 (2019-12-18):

Arduino PlatformIO

jvoermans, 2019-12-18:
Hi Jean,

I installed VScode with PlatformIO extension on Linux system. I tried to upload the code onto the Arduino, but get some errors. Any suggestions? Below is terminal messages

> Executing task in folder ArduinoMega: platformio run <

Processing megaatmega2560 (platform: atmelavr; board: megaatmega2560; framework: arduino)
--------------------------------------------------------------------------------------------------------------------------------------------------------------------------------------------
Verbose mode can be enabled via `-v, --verbose` option
CONFIGURATION: https://docs.platformio.org/page/boards/atmelavr/megaatmega2560.html
PLATFORM: Atmel AVR 2.0.0 > Arduino Mega or Mega 2560 ATmega2560 (Mega 2560)
HARDWARE: ATMEGA2560 16MHz, 8KB RAM, 248KB Flash
PACKAGES: toolchain-atmelavr 1.50400.190710 (5.4.0), framework-arduino-avr 5.0.0
Converting src.ino
LDF: Library Dependency Finder -> http://bit.ly/configure-pio-ldf
LDF Modes: Finder ~ chain, Compatibility ~ soft
Found 7 compatible libraries
Scanning dependencies...
Dependency Graph
|-- <EEPROM> 2.0
|-- <Adafruit GPS Library> 1.3.0
|   |-- <SPI> 1.0
|   |-- <SoftwareSerial> 1.0
|   |-- <Wire> 1.0
|-- <SoftwareSerial> 1.0
|-- <SPI> 1.0
|-- <Wire> 1.0
|-- <SD>
|   |-- <SPI> 1.0
Building in release mode
Compiling .pio/build/megaatmega2560/src/src.ino.cpp.o
In file included from src/IridiumManager.h:2:0,
                 from /home/joey/Documents/UniMelb/Ice_Logger/ArduinoMega/src/src.ino:44:
src/IridiumSBD.h: In constructor 'IridiumSBD::IridiumSBD(Stream&, int)':
src/IridiumSBD.h:161:18: warning: 'IridiumSBD::lastPowerOnTime' will be initialized after [-Wreorder]
    unsigned long lastPowerOnTime;
                  ^
src/IridiumSBD.h:145:15: warning:   'IridiumSBD::StreamShim IridiumSBD::diag' [-Wreorder]
    StreamShim diag;
               ^
src/IridiumSBD.h:88:4: warning:   when initialized here [-Wreorder]
    IridiumSBD(Stream &str, int sleepPinNo = -1) :
    ^
src/IridiumSBD.h: In constructor 'IridiumSBD::StreamShim::StreamShim(IridiumSBD*, bool)':
src/IridiumSBD.h:123:19: warning: 'IridiumSBD::StreamShim::isbd' will be initialized after [-Wreorder]
       IridiumSBD *isbd;
                   ^
src/IridiumSBD.h:122:12: warning:   'bool IridiumSBD::StreamShim::diags' [-Wreorder]
       bool diags;
            ^
src/IridiumSBD.h:126:7: warning:   when initialized here [-Wreorder]
       StreamShim(IridiumSBD *isbd, bool d) : isbd(isbd), diags(d) {}
       ^
In file included from src/EEPROM_interaction.h:2:0,
                 from src/SDManager.h:3,
                 from src/GPSManager.h:6,
                 from /home/joey/Documents/UniMelb/Ice_Logger/ArduinoMega/src/src.ino:40:
/home/joey/Documents/UniMelb/Ice_Logger/ArduinoMega/src/src.ino: At top level:
/home/joey/.platformio/packages/framework-arduino-avr/libraries/EEPROM/src/EEPROM.h:145:20: warning: 'EEPROM' defined but not used [-Wunused-variable]
 static EEPROMClass EEPROM;
                    ^
Linking .pio/build/megaatmega2560/firmware.elf
lto1: internal compiler error: in lto_output_varpool_node, at lto-cgraph.c:624
Please submit a full bug report,
with preprocessed source if appropriate.
See <http://www.atmel.com> for instructions.
lto-wrapper: fatal error: avr-g++ returned 1 exit status
compilation terminated.
/home/joey/.platformio/packages/toolchain-atmelavr/bin/../lib/gcc/avr/5.4.0/../../../../avr/bin/ld: error: lto-wrapper failed
collect2: error: ld returned 1 exit status
*** [.pio/build/megaatmega2560/firmware.elf] Error 1
================================================================================ [FAILED] Took 0.95 seconds ================================================================================
The terminal process terminated with exit code: 1

Terminal will be reused by tasks, press any key to close it.

jerabaul29, 2019-12-18:
Mmh, strange, I have never seen something like that myself. As you have seen the code compiled nicely on my laptop. Have you tried googling the issue / asking for help online / filling in the bug report?

jerabaul29, 2019-12-18:
(I am traveling at a conference in China, not easy for me to help debug just now. What is the deadline for assembly of your instrument?)

jerabaul29, 2019-12-18:
Which code are you trying to compile? This one right?

https://github.com/jerabaul29/LoggerWavesInIce_InSituWithIridium/tree/master/DevelopmentCode/ArduinoMega/src

You should compile from the src.ino if I remember well.

Worst case if you cannot compile, can you try to use the binary in the .build folder and upload it on the mega without recompiling? You should look for instructions if / how this can be done on platformio (if needed ask for help / open an issue).

jvoermans, 2019-12-18:
Deadline is the end of the month.

I find it a bit confusing. I tried a simple led blink sketch, which uploads to the arduino uno and mega fine through the arduinoIDE. Through platformioIO, it only works for the uno, but not the mega. Then you get the error message:
avrdude: stk500_recv(): programmer is not responding

Seems to be very generic error message, haven't solved that one yet.

I prefer to use platformio as it seems easier to compile, but can I do the same with the arduinoIDE if I restructure the folders and use the extended buffer again?

jerabaul29, 2019-12-18:
Mmh, ok. It is often quite some 'emotions' with assembling hardware on your own for the first time with tight deadlines, but I can do my best to help.

It sounds like there is a very fundamental step in the setup of platformio for the mega that must have a problem.

- are you sure you have installed all necessary packages / dependencies for platformio working with the Arduino Mega?

- are you sure you have selected the right parameters in the code setup so that paltformio us aware it should talk to a mega? There is at least 1 maybe more places in platformio where you have to select Mega from a menu. Also, there may be different kinds of mega, I think if I remember well you have to select mega 2560 or something like that.

jerabaul29, 2019-12-19:
@jvoermans just to illustrate how things look like on my computer (see the options on the lower bar):

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

One more thing: the first time I tried to compile I got an error message for some strange reason, a bit in the same kind of you. But trying to compile one more time, without changing anything, fixed the problem somehow. Can you try to launch compilation a couple of times? You can try first to compile, not upload.

jvoermans, 2019-12-19:
I can open the src.ini file, but do get the following popup message:

C/C++ IntelliSense service does not support .INO files. It might lead to the spurious problems with code completion, linting, and debugging. Please convert .INO sketch into the valid .CPP file.

I already tried compiling multiple times, but get same error message. I think it is not recognizing the board somehow.
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

jerabaul29, 2019-12-19:
- The intellisense error message is not a problem. This just means that the intelligent code completion will not work with .ino files, and that it is recommended to change it into a .cpp file instead.

- Have you tried to troubleshoot with help from the internet? Can this help?

https://github.com/platformio/platform-atmelavr/issues/65

Are you using linux or windows? This looks like windows from your command line output. Many things that are open source do not like windows and break on it. Can you try with a linux computer instead?

- Have you tried to report the bug as suggested? This is related seems to a compiler that was broken. People have god some help on that before:

https://github.com/arduino/arduino-builder/issues/332

https://github.com/arduino/Arduino/issues/7949
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
jvoermans, 2019-12-20:
Nope. Also Linux same issue. A simple sketch through platformio can be uploaded on the mega2560.

I tried now to do all with the ArduinoIDE. I managed all the libraries, but it says it cannot find the 'parameters.h' file, while it is clearly in the folder.

Arduino: 1.8.4 (Linux), Board: "Arduino/Genuino Mega or Mega 2560, ATmega2560 (Mega 2560)"

In file included from sketch/HighSpeedUSBOutputController.cpp:2:0:
/home/joey/Arduino/libraries/DebugMacros_Lib/DebugMacros.h:2:24: fatal error: parameters.h: No such file or directory
 #include "parameters.h"
                        ^
compilation terminated.
exit status 1
Error compiling for board Arduino/Genuino Mega or Mega 2560.

Does this mean I have to add the 'parameters.h' header in the DebugMacros library folder? that sounds a bit weird to me, if I do, I get quite a few other errors

jerabaul29, 2019-12-21:
@jvoermans it should work now:

- I have put a separate folder here that should compile under arduino ide:

https://github.com/jerabaul29/LoggerWavesInIce_InSituWithIridium/tree/master/DevelopmentCode/ArduinoMega_commit6cec5acdf/src

# solution 1: compile locally

- You can compile / upload yourself if you want through the Arduino IDE. For this, you need to update the size of the buffers first. For this, you should find the location of your arduino core, and then go to:

**locations_of_install/arduino-1.8.10/hardware/arduino/avr/cores/arduino**

and there modify the *HardwareSerial.h* to:

```
#if !defined(SERIAL_TX_BUFFER_SIZE)
#if ((RAMEND - RAMSTART) < 1023)
#define SERIAL_TX_BUFFER_SIZE 16
#else
#define SERIAL_TX_BUFFER_SIZE 512
#endif
#endif
#if !defined(SERIAL_RX_BUFFER_SIZE)
#if ((RAMEND - RAMSTART) < 1023)
#define SERIAL_RX_BUFFER_SIZE 16
#else
#define SERIAL_RX_BUFFER_SIZE 512
#endif
#endif
```

(i.e. 2 values of 64 changed to 512). In this case, the compilation should give something like:

```
Sketch uses 28672 bytes (11%) of program storage space. Maximum is 253952 bytes.
Global variables use 6949 bytes (84%) of dynamic memory, leaving 1243 bytes for local variables. Maximum is 8192 bytes.
Low memory available, stability problems may occur.
```

This confirms that a lot of RAM is used because the buffers have been extended.

# solution 2: upload the hex I compiled and put on the repo

- Another solution is to use directly the .hex file I have uploaded on the repo. Not sure though if you should use:

https://github.com/jerabaul29/LoggerWavesInIce_InSituWithIridium/blob/master/DevelopmentCode/ArduinoMega_commit6cec5acdf/src/src.ino.mega.hex

or:

https://github.com/jerabaul29/LoggerWavesInIce_InSituWithIridium/blob/master/DevelopmentCode/ArduinoMega_commit6cec5acdf/src/src.ino.with_bootloader.mega.hex

and to upload it on your arduino mega using XLoader (I have not tried myself before, but should be ok).

How I generated the .hex files:

https://arduino.stackexchange.com/questions/48431/how-to-get-the-firmware-hex-file-from-a-ino-file-containing-the-code

How it should be possible to upload with XLoader:

http://www.hobbytronics.co.uk/arduino-xloader

jvoermans, 2019-12-21:
Thanks Jean for your help. I used the first solution. First upload the initializeEEPROM, then use the extended buffer core to upload the src. Get almost the exact numbers you get:

Sketch uses 28678 bytes (11%) of program storage space. Maximum is 253952 bytes.
Global variables use 6949 bytes (84%) of dynamic memory, leaving 1243 bytes for local variables. Maximum is 8192 bytes.
Low memory available, stability problems may occur.

I'll test tomorrow at uni.

Could you tell me what is different with this folder compared to the other? The compiling goes almost instantly, is it actually compiling or does it bypass and uses info from the hex file?

jerabaul29, 2019-12-21:
Perfect, great that it works!

I think it does do the compilation, no tricks here :) I just fixed a few things in the source code. Keep me informed if it works.

jerabaul29, 2019-12-24:
This seems to work, closing.

Closed 2019-12-24.

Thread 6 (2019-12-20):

building instruments

jerabaul29, 2019-12-20:
@jvoermans how are things going?

- power controller is ok, right?
- how is it going with RPi image?
- how is it going with Mega code upload?

:)

jvoermans, 2019-12-24:
I tried to start the loggers we finished in Oslo, but they act differently. I think it is the battery I used (I connected it to 2x AA batteries). Measuring the voltage across the step-up converter seems alright, but when the logger is supposed to log, the GPS keeps blinking for 1-2 minutes, then the SD card finally started recording, and at the end of the 25 minutes of recording, it started blinking with lower frequency. After 25 min it stopped (as usual) but the RPi never started. I checked the file, the accelerometer data seems fine, and all in the file, but the last part a lot of zeros popup and infrequently it gives accelerometer data. The fact that it starts recording (irrespective of the RPi doing its work), does that mean that the RPi is successfully identified by the arduino, that is, would it start recording when the RPi is not attached?

Do you think the battery is the issue?

When I use the 'logger in ice' (without iridium), and connect to the computer, everything works normal. So I think its the battery. It's Christmas here, so can't get a proper battery right now to test, so have to wait for that unfortunately. If you ever experienced something like the described, let me know.

jvoermans, 2019-12-24:
Also, I used a 1000uF (16V) rather than 1000uF (10V) capacitor and a 1uF (63V) instead of 1uF (50V), (electro guys said it wouldn't matter for the Arduino). Would you agree?

jerabaul29, 2019-12-24:
- The capacitors make no difference at all, agree with your engineers :)

- Yes, I think your batteries are too weak. Can you try 3 X AA in series? The problem is that AA nominal voltage is 1.5V, actually closer to 1.4V, so 2.8V total. In addition when you add voltage drop due to internal resistance you may be down to maybe 2.75 or 2.7 V. In this case, the logger may automatically shut off when a large load (RPi) wakes up, and / or the voltage may drop too low and things start to fail. I think this may also explain for your strange data. Also, those batteries have very little capacity, so they may be quite depleted (and then ever lower voltage) by the time the RPi wakes up. When the RPi is on the intensity draw on the batteries may be up to 1.5 or 2 A, which is a lot for so small cells.

- which RPi model do you use? The same you had to Oslo? Do you see some of the LEDs of the RPi turning on at some point at all?

- Can you use a lab power supply at 3.1V as input to you logger prototype rather than batteries?

jerabaul29, 2019-12-24:
PS: still getting data from Antarctica?

Merry Christmas! :)

jvoermans, 2019-12-24:
Yes, they are still working and still full battery. Still no waves though :p but at this rate they can survive for a long time.

I'll ask if they have bench power supply, how many amps should I use with 3.1V?

Jij ook vrolijk kerstfeest!

jerabaul29, 2019-12-24:
Excellent, so happy with the successful deployment, that really makes me happy 🎉🎉 Hope for sun to keep the batteries happy, no snow falls to not cover the antenna, and some waves some time soon!

You should use a lab supply, put it in 'set voltage' at 3.1V, and put a max intensity at 5A or something like this. I.e. it should be voltage regulated without any intensity limit in practice (high enough to not limit).

jvoermans, 2019-12-30:
Surprisingly, still not working!

I used a bench power supply, 3.3V, max 5A.

This is what happens:
-everything goes normal, after few reconnections of battery, logging occurs rather quickly as it should be, current drawn about 0.2A for 25 min.
-Then for 5-6 minutes, nothing really happens with the RPi, only GPS breakout blinks normally, and the current stays around 0.3A, and every 20 seconds, it increases in 1-3 seconds to 0.5A after which it drops back to 0.3A
-After that, the green light starts burning of the RPi, this takes 2 minutes.
-Then RPi doesn't do anything, only GPS breakout blinks for about 10 seconds and the sequence is over.

One thing, I accidentally mixed up the SD-cards of the RPi's. Is that an issue? I rotated all three SDcards of the RPi to see if anything changes but they all lead to the same result.

Also, accelerometer data files are fine on the SDcard of the breakout. They are not present on the RPi, so they were not transferred to the RPi.

Also, is it normal that the logger can log even without the RPi being attached? This is not the case for the Iridium, if I detach that one, it won't start logging...

jerabaul29, 2019-12-30:
Ok.

This sounds like everything is fine until the RPi and the Mega should talk. Somehow they do not manage to talk to each other, this is when the sequence is aborted.

Are you well connecting the RPi and the Mega with an USB cable? Have you checked that the USB cable is 'good' (can you upload an Arduino sketch through it for example? Some USB cables are 'dummies' that only transfer power, no data).

Yes, it is expected that the loggers work without RPi, bug not without Iridium.

Are you sure you correctly burned the image on the SD card following the instructions? Can you just give power to a RPi through the mini USB and let it boot, and check that both the green and red lights blink then?

Which model of RPi are you using? Is it the same as you used when in Oslo?

Eiserklaus, 2019-12-30:
Hi,

I have no hardware here to test anything (as mentioned I left Labmaker) but my 2 cents: intermittent fails of Raspis are most often power issues. I experienced fails in one of my projects each time the USB wifi tried to send due to insufficient power. So my idea would be to power the Arduino separately (if it is not) and try perhaps a large capacitor in the power supply to bridge peak power consumption. Same considerations may hold true for other power intensive components like the Iridium.
Also removing all useless (power-) LEDs on the Raspi and Arduino may help to some extent.

jerabaul29, 2019-12-30:
Yes, power is always a possible issue. But we know that with steady 3V input this setup should work fine... Wonder if there is another problem: RPi version, SD card preparation, faulty USB cable or other.

jerabaul29, 2019-12-31:
Ok, looks like this does is a power issue encountered when using a lab power supply instead of a battery, strange. Probably the step up converter does not like having an input with any ripples or something like that. Will investigate with pololu. @jvoermans let us know when you have sent the message to them.

jerabaul29, 2020-01-02:
@jvoermans can you confirm this was due to wrong settings of your power supply, and that the new series of instruments you built and programmed works fine? If this is well the case feel free to close.

jvoermans, 2020-01-02:
Haven't been able to test the settings of the power supply yet. Most likely, problem is the power supply, increasing the voltage of the bench power supply to 4.5V led to a steady input voltage of 5.2V on the PCB (both with Arduino active and inactive).

jerabaul29, 2020-01-02:
There should be a way to set the max current of the supply and increase it to a few amps, enough to power at 3.2V. Can you ask your engineers for help? Should do the trick.

jvoermans, 2020-01-02:
I think the max current is standard at 5.2A. When you turn on the supply, it shows briefly the current settings. But I have to double check. I'll get back on this.

jerabaul29, 2020-01-02:
5.2 A should be enough at 3.2V. I would think there is a restriction on it now. May be wrong though.

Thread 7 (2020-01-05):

Iridium transmission

jvoermans, 2020-01-05:
@jerabaul29
is the RPi or the Arduino responsible for the final transmission of data? i.e. if I want to send temperature through Iridium as well, perhaps easiest to do with the GPS data transmission, what files should I start?

Is that in the 'IridiumManager.cpp' file?

jerabaul29, 2020-01-05:
The Arduino is responsible. Yes, it is this file. I let you look at the code to get started. Basically, you need to 1) write the day in the TX buffer of the Iridium 2) ask to send.

Eiserklaus, 2020-01-08:
Hi,

Hi, would this module be of any value for your research:
https://www.taoglas.com/product/edge-locate/

jerabaul29, 2020-01-08:
Hi,

This could be of interest for measuring very low frequency waves, but I think the IMU is a bit better in our case (we manage to measure waves of a few mms, but this has a cm resolution only).

Closed 2021-11-06.

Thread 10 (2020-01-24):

enhancement: I2C power / Mega

jerabaul29, 2020-01-24:
Would be great to have the Power and Mega parts talk through I2C, instead / in addition to the simple wire information.

Closed 2021-11-06.

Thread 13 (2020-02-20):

TODO: add a 'solar power energy dissipation' mechanism

jerabaul29, 2020-02-20:
It is stupid / sad to waste electrical energy produced in excess by the solar panel by simply disconnecting it when the battery is cold. This energy would better be used to simply add a bit of heat inside the pelican case. TODO: add a MOSFET-controlled dissipation resistance on the power management module, so as to be able to switch on dissipation of up to around 5W of electrical power when the battery is full and the solar panel productive.

Closed 2021-11-06.

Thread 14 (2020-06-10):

TODO: add on / off switch

jerabaul29, 2020-06-10:
Add on / off switch:

- off makes sure all caps are emptied to avoid browned-out protection and failure to start
- on makes everything on.

Closed 2021-11-06.

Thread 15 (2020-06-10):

check battery protection

jerabaul29, 2020-06-10:
it is possible that there is a problem with battery protection; check.

Closed 2020-08-20.

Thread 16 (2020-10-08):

ArduinoMega

jvoermans, 2020-10-08:
@jerabaul29 I've been trying to get the code on the ArduinoMega, this time I attempted through VSC again, but there is an error that pops up everytime:
C:\Users\jvoermans\.platformio\lib\Adafruit GPS Library_ID20\src/Adafruit_GPS.h:58:28: fatal error: SoftwareSerial.h: No such file or directory

jerabaul29, 2020-10-08:
You need to put the Software Serial in the lib folder. Just put the whole content of

https://github.com/arduino/ArduinoCore-avr/tree/master/libraries/SoftwareSerial

In lib in the project and let me know if it works.

jvoermans, 2020-10-08:
I added SoftwareSerial folder and the h/cpp files in the lib folder, but still get the same error. See figure attached.

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

jerabaul29, 2020-10-08:
Mmh, strange, are you sure that the whole Software serial is in the lib folder? I.e. do you well have the liv/SoftwareSerial/src and everything there?

# possible fix 1

A possibility is that you may need to change to ```#include "SoftwareSerial.h"``` here:

https://github.com/jerabaul29/LoggerWavesInIce_InSituWithIridium/blob/7bb2ff9ef0ba867dc73101b6fbd4b49d061ea94f/DevelopmentCode/ArduinoMega/src/GPSManager.h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

# possible fix 2

Otherwise, can you follow the advice, and install directly through the platformio software dependency manager as suggested in the output?

# best to "keep it as it was working before"

But you were able to compile this before as you already built some loggers, right? Can you just use the exact same method as what you used and was working before? I set this up a long time ago, I may have been a bit sloppy with the dependencies management, I will try to be more consistent on newer code.

jvoermans, 2020-10-08:
Yes, uploading through the Arduino IDE  you provided works absolutely fine. But I wanted to move to VSC so tried again.

The above didn't work either, however, I added 'lib_ldf_mode = deep' to the platformio.ini file did the trick
https://community.platformio.org/t/build-fails-because-missing-library-include-arduino-framework/14146/2

I end up with a different error now, it looks quite familiar, I think this is where I ended last time with the errors 'ld.exe: error: lto-wrapper failed'. I'll just working from the IDE then for this one

jerabaul29, 2020-10-09:
Ok, sounds good! Yes it works on my Plarformio, not sure why not on yours. I suppose I installed some libraries globally on my machine. I will not do this in the future ,but always put stuff in the lib folder, this way it will be fully reproducible :) .

Ok, good luck!

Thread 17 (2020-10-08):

Extended Buffer

jvoermans, 2020-10-08:
To get back to this topic. I was re-attempting to get the extended buffer working on my work laptop again (Windows 10), and finally figured out why it wasn't working. Apparently, Windows 10 has a hidden Arduino folder in 'AppData'. If you go to File-->Preferences in the Arduino IDE, there is at the bottom a location where the Arduino 'preferences' are stored. Here is another folder with all the boards, cores etc. I'm sure you can change the settings of that somewhere, but changing it in the 'AppData' folder works fine for me. Anyway, not relevant for you on Linux, but perhaps good to document.

I had a question regarding which files you have to change the buffers. Is it just in the HardwareSerial.h, as you stated earlier:
https://github.com/jerabaul29/LoggerWavesInIce/tree/master/ArduinoMegaExtendedSerialBuffers

Or also in the 'USBAPI.h' as stated in another source:
https://www.hobbytronics.co.uk/arduino-serial-buffer-size

jerabaul29, 2020-10-08:
I do not have access to a Windows computer and cannot help debug on Windows platforms.

Do you have access to a Linux computer? That would be the simplest. If not, can you ask Alexander to buy for your lab a Thinkpad T490 or similar, put Ubuntu 20.04 on it, and use it as "the lab's Ubuntu machine"? It is a pain to write code on Linux and make sure it works on Windows...

My post should be a good description of what I did. That was a long time ago though, I do not remember everything.

For this specific project: you had a successful method for uploading the code on the Mega as you built several instruments last year, right? :) Can you continue with this method (the "don t fix it if it s not broken", apologies ^^). This code starts to be quite old, I do not really want to spend to much time supporting it, would prefer to re-develop something much cleaner.

jerabaul29, 2020-10-08:
See this:

https://github.com/jerabaul29/LoggerWavesInIce_InSituWithIridium/issues/4

jvoermans, 2020-10-08:
All good

Closed 2020-10-08.

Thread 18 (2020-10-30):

Add sensors

jvoermans, 2020-10-30:
@jerabaul29 Hi Jean, trying to explain my approach on how to change the sketch to have the first Iridium message include mean temperature from a  sensor. Could you guide me in whether this is ok to do?

(1) measure temperature directly after logging has finished. So some lines to record temperature over, say 2 minutes, comes in between these lines:

https://github.com/jerabaul29/LoggerWavesInIce_InSituWithIridium/blob/7bb2ff9ef0ba867dc73101b6fbd4b49d061ea94f/DevelopmentCode/ArduinoMega_commit6cec5acdf/src/src.in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

(2) Store the mean temperature in a variable, for example: TEMP_AVE

(3) Add lines to the 'message to be send'. Probably copying and editing this:
https://github.com/jerabaul29/LoggerWavesInIce_InSituWithIridium/blob/7bb2ff9ef0ba867dc73101b6fbd4b49d061ea94f/DevelopmentCode/ArduinoMega_commit6cec5acdf/src/Iridiu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
If the temperature is stored under a variable "TEMP_AVE", can I just say:
String TEMP_AVE_string = String{TEMP_AVE};  ?

(4) Add something similar as this in the header file:
https://github.com/jerabaul29/LoggerWavesInIce_InSituWithIridium/blob/7bb2ff9ef0ba867dc73101b6fbd4b49d061ea94f/DevelopmentCode/ArduinoMega_commit6cec5acdf/src/Iridiu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

Am I forgetting something? while this increases the bytes of the message, there is no problem technically I assume?

jerabaul29, 2020-10-30:
Yes, exactly, that should be all what you need to do. A few notes:

- you should develop your code on a new branch, forked from the commit ```39c30775849a```. I created just a branch just now, so you can work directly on it :) https://github.com/jerabaul29/LoggerWavesInIce_InSituWithIridium/tree/feat/add-temp-meas

- remember to regularly reset the watchdog if you have code running some logging for a long amount of time. The command is simple: ```wdt_reset();```

- you will also need to tune a bit the python code for deciphering the iridium messages, but that should be fine.

Yes, there should be plenty of space left on the status message for adding this information.

One more thing: I do not really think that you need to take the average over such a long periods. If the measuring time is 10 ms, maybe it should be enough to average over 100 measurements ie 1 second?

jvoermans, 2020-10-30:
Thanks. You might have explained already, but what is the watchdog exactly?

jerabaul29, 2020-10-30:
It resets and reboots the board if not called regularly. The ```wdt_reset()``` command is what resets it, confirming that the program is running well without hanging.

https://circuits4you.com/2018/01/24/tutorial-on-arduino-watchdog-timer-setup/

jvoermans, 2020-11-03:
Ok I was able to get temperature in the GPS Iridium message. In a separate clone of the repo I did last week.

To work from the branch instead, I cloned the 'feat/add-temp-meas' branch. I added the word 'test' in the readme file of the branch, and tried to push it, but I get a 'unable to access' error. Do I need permission from you I guess to push it?

jerabaul29, 2020-11-03:
That sounds excellent, congratulations!

I think you may need actually to perform a pull request since this is a public repo. See:

https://docs.github.com/en/free-pro-team@latest/github/collaborating-with-issues-and-pull-requests/about-pull-requests

https://docs.github.com/en/free-pro-team@latest/github/collaborating-with-issues-and-pull-requests/creating-a-pull-request

https://yangsu.github.io/pull-request-tutorial/

Basically when there is a public repo, there are not always collaborators as in a private repo, and to make it possible for everybody to participate but for the owner to still have control, there is this pull request system. It works very well :)

Let me know if anything is unclear.

jerabaul29, 2020-11-03:
(note: you may need to create a public fork before you can do a pull request; may be easier to just fork first, then copy paste your changes anew, and then do a pull request).

Closed 2021-11-06.

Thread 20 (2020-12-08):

3.3V pin

jvoermans, 2020-12-08:
@jerabaul29 I think the 3.3V pin is not connected to anything right? So I can use it for 3.3V sensors?

jerabaul29, 2020-12-08:
Mmh, which pin? Arduino Due 3.3V? Yes, it should be a stable and safe 3.3V source. Why? :)

jvoermans, 2020-12-08:
No, the mega 3.3V pin. We solder it but I don't think I see it going anywhere. The temperature sensors of blue robotics each need an I2C level converter for 5V to 3.3V (supply voltage 5V is fine, but logic needs maximum 3.6V), so this problem is for mega only. But the converters of bluerobotics are relatively big and expensive compared to others as they have two easy click sockets which I won't use:
https://bluerobotics.com/store/comm-control-power/tether-interface/level-converter-r1/

Sparkfun has this one:
https://www.sparkfun.com/products/12009

but it needs a reference Voltage of 3.3V.

jerabaul29, 2020-12-09:
Yes, sorry, I was answering too many issues in bulk and had not noticed this was on another repo :)

So basically:

- yes, feel free to use the 3.3V as a powering pin. It is obtained by a low dropout regulator tapping on the 5V rail. It is perfectly fine to use it :)

- I think the sparkfun adapter looks very good. Should work out of the box without problem. Make sure to test it in details :)

Let me know if you have any problems.

Closed 2021-11-06.

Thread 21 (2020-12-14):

Interrupt

jvoermans, 2020-12-14:
@jerabaul29 Is there going to be a conflict somewhere in the software if I use 'attachInterrupt' to measure wind speed?  I'm not an expert on the interrupt function, but it seems it can conflict easily with other processes running on the background...

jerabaul29, 2020-12-15:
Mmh, I do not think it should, as the interrupt will be on the specific pin you attach to. There are many interrupt handlers routines, so that it is possible to have several interrupts defined at the same time. Would be best to test and check of course, but I would guess this should work :) .

Let me know when you test and how. Maybe you can create a separate project for this feature, and I can take care of putting in the main code? :)

Closed 2021-11-06.

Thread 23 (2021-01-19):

using 32GB card image

jerabaul29, 2021-01-19:
@jvoermans let's discuss here how it goes with using the 32GB card image.

jvoermans, 2021-01-20:
initially solved. Will do test today...

jvoermans, 2021-01-20:
You remember when the instrument was deployed in the Antarctic and only GPS messages came through, not the spectra? I first thought the SD card of the RPi was full (which is why I wanted to make sure this time I increased the size). I now actually think the battery is starting to get empty and cannot handle the RPi anymore, draws too much current, and voltage drops to about 3.6V instead of 5.1-5.2V. So, until the RPi is started, everything works fine, but from there on not anymore...

jvoermans, 2021-01-21:
Works!

jvoermans, 2021-01-21:
Am I missing the 'close' button somewhere? Or are you the only one able to do so? ;)

jerabaul29, 2021-01-21:
Mmh no you should be able to close too. See the button left to Comment :) .

Great that it works :) .

jvoermans, 2021-01-22:
That's what I though. I might be crazy...
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

jerabaul29, 2021-01-22:
Really weird. I will close then.

Closed 2021-01-22.

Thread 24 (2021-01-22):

Low memory

jvoermans, 2021-01-22:
@jerabaul29 Is it possible that the low memory (i.e. ~90% of dynamic memory is used and low memory warning is given) is a problem when adding more sensors? The sketch compiles fine, the logger starts, but does not record (i.e., after 6 blinks of the GPS unit, the SD card doesn't start recording).

For example, if I add 3 temperature probes and the sonar, it works. But when I add the pressure sensor, it doesn't. Removing one temperature probe and adding the pressure sensor back and it works again...

jerabaul29, 2021-01-23:
Mmmh, it is possible. I never thought about adding so many sensors... Is it ok to limit just a bit the number of sensors so that things work?

On the instruments V3 that I think of I will use a board with much, much more memory that has become available only very recently. This will solve this kind of problems...

I think you may consider which sensors to put on this Vs the new Due loggers. For example maybe the sonar would be better on the due, recording both distance and full ping profile as I am working on? ... I have some compilation problems at the moment but will look at it this WE.

jvoermans, 2021-01-24:
Ah ok. Yes, I guess pressure sensor can go. It is least important to the experiments. Although Meteorologists are especially interested in that...

I find that 7493 bytes of dynamic memory is more or less the threshold, though it seems to differ a bit. I think I'm short about 10-20 bytes to get all sensors in. Btw, can I change the String below into: String(F("B,\n") ?
That would give me 4 bytes... Or does this mess things up?

For example,:
https://github.com/jerabaul29/LoggerWavesInIce_InSituWithIridium/blob/7bb2ff9ef0ba867dc73101b6fbd4b49d061ea94f/DevelopmentCode/ArduinoMega_commit6cec5acdf/src/VN100M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

jerabaul29, 2021-01-24:
No I do not think you should change that, as this is used by the RPi parsing. I will go through the code quickly now and look for possibilities to reduce memory use. I let you know.

jerabaul29, 2021-01-24:
Ok, a few tips for freeing a bit extra memory. Note that this will change some buffers sizes etc, so you should definitely test before deciding if things work. Are you well compiling from platformio, or from something else?

To get a bit extra available memory:

- Start from the code for the "working" Due code as usual: commit **39c30775849a** .

- The main place with potential for reducing the memory consumption is the serial buffers. As said, it is a bit tricky to reduce, and may have unexpected consequences, so you should double check carefully that things still work after. To reduce a bit the memory consumption, you should modify the ```platformio.ini``` file, at the root of ```LoggerWavesInIce_InSituWithIridium/DevelopmentCode/ArduinoMega/src```. There, the critical values are the ones in:

```
build_flags = -D SERIAL_RX_BUFFER_SIZE=512 -D SERIAL_TX_BUFFER_SIZE=512
```

You could try for example the following values:

- quite tough reduction:  ```build_flags = -D SERIAL_RX_BUFFER_SIZE=400 -D SERIAL_TX_BUFFER_SIZE=400```
- if the previous reduction does not work, can try a less hard reduction: ```build_flags = -D SERIAL_RX_BUFFER_SIZE=450 -D SERIAL_TX_BUFFER_SIZE=450```

Let me know how this goes. I think that the first solution has a good chance to work, and then you should get plenty of RAM back (on the order of slightly under 1KB extra available RAM). If it does not work fine, then the second one may do. If the second one does not work either let me know.

jerabaul29, 2021-01-24:
I just tested the configuration with size ```400```, it should free about 10% of the RAM. I think it *should* work fine, but let me know how tests go.

Closed 2021-11-06.

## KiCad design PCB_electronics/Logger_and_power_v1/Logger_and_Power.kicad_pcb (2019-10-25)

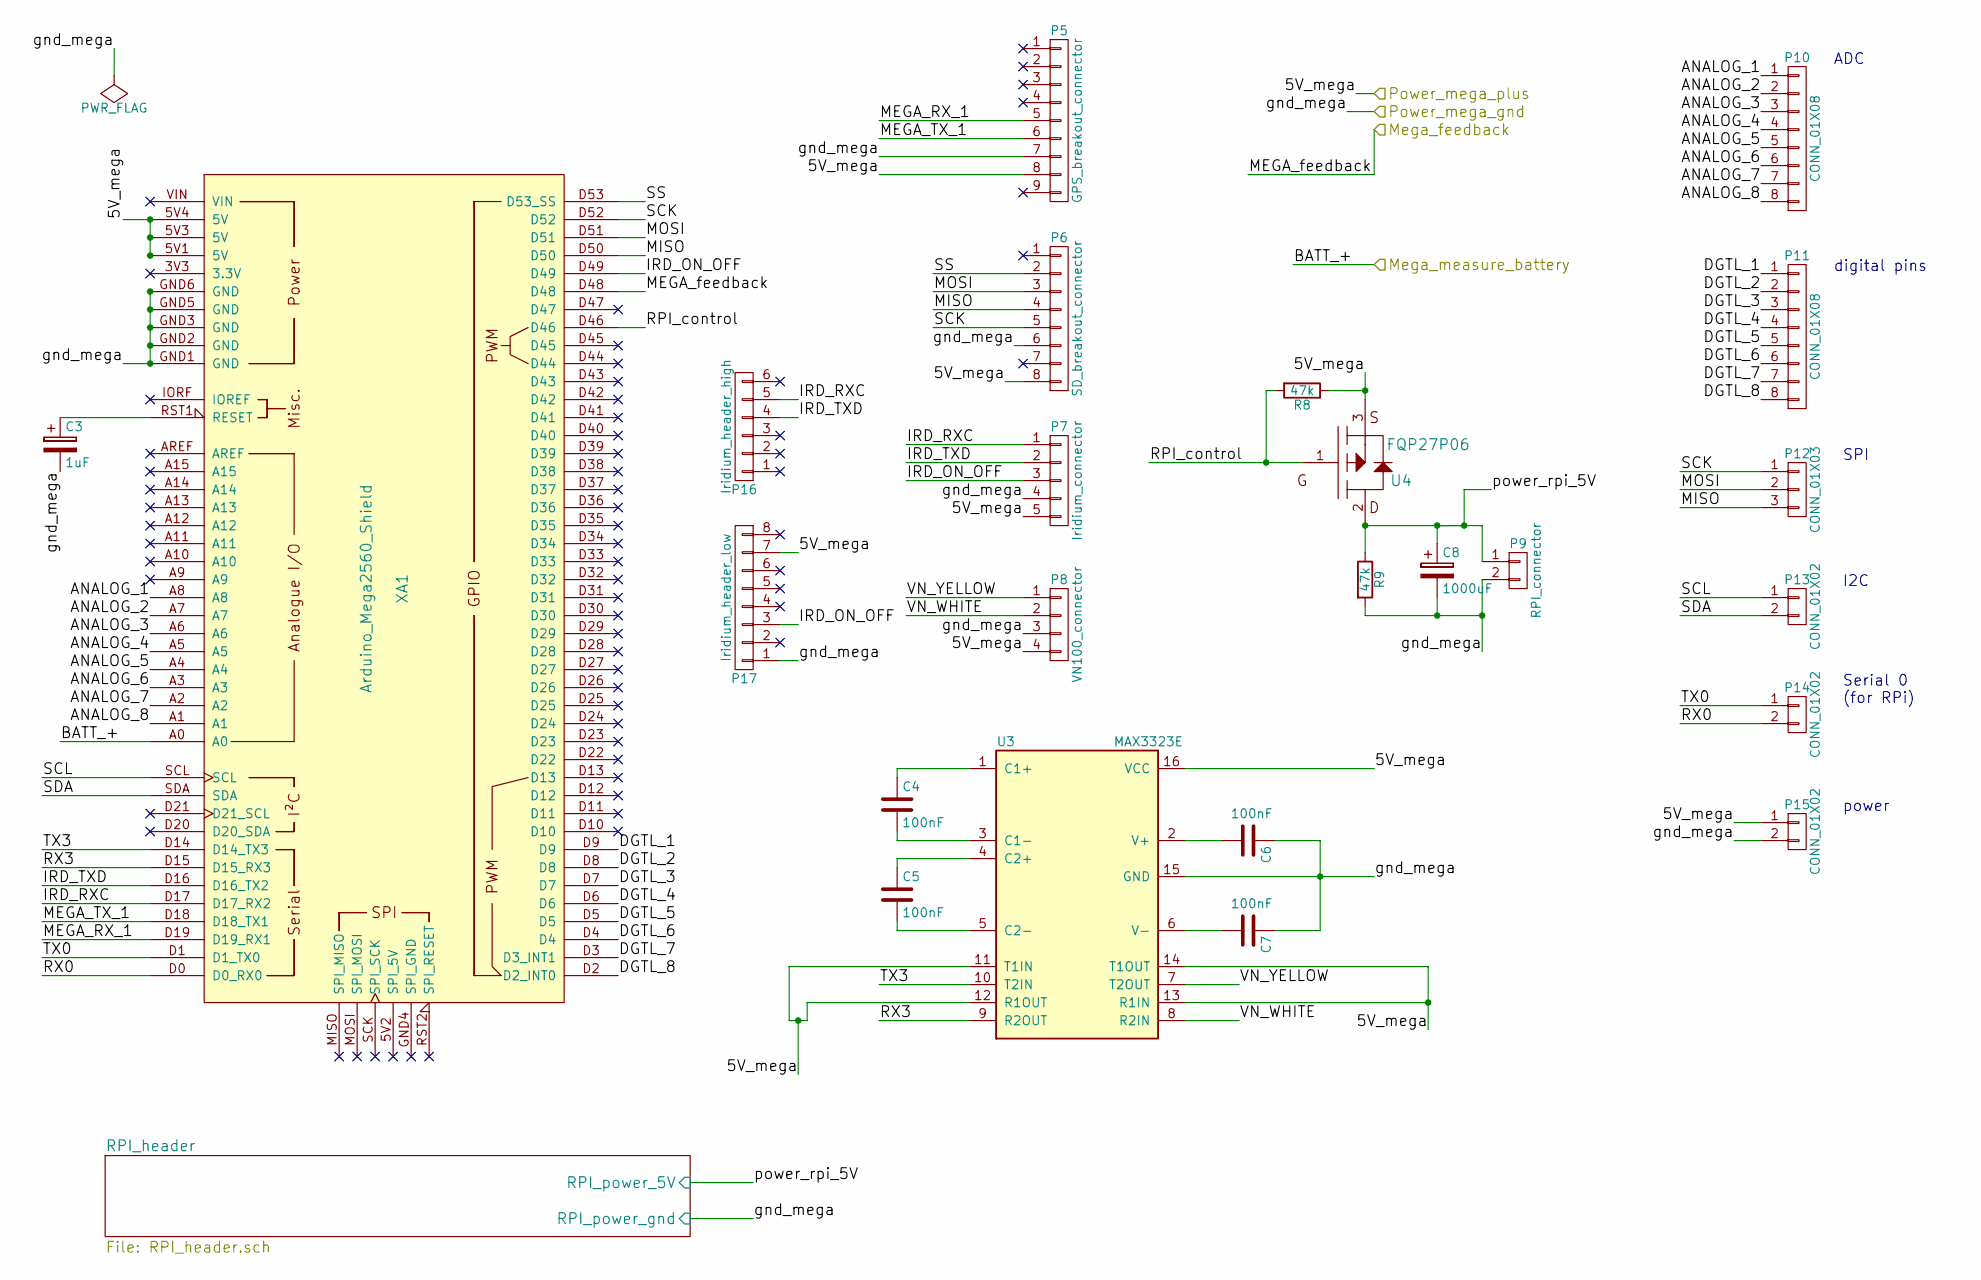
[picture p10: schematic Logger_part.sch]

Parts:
C3: 1uF; C_Radial_D8_L11.5_P3.5
C4, C5, C6, C7: 100nF; C_Disc_D3_P2.5
C8: 1000uF; C_Radial_D8_L13_P3.8
P5: GPS_breakout_connector; Pin_Header_Straight_1x09
P6: SD_breakout_connector; Pin_Header_Straight_1x08
P7: Iridium_connector; Pin_Header_Straight_1x05
P8: VN100_connector; Pin_Header_Straight_1x04
P9: RPI_connector; Pin_Header_Straight_2x01
P10, P11: CONN_01X08; Pin_Header_Straight_1x08
P12: CONN_01X03; Pin_Header_Straight_1x03
P13, P14, P15: CONN_01X02; Pin_Header_Straight_2x01
P16: Iridium_header_high; Pin_Header_Straight_1x06
P17: Iridium_header_low; Pin_Header_Straight_1x08
R8, R9: 47k; Resistor_Horizontal_RM10mm
U3: MAX3323E; DIP-16_W7.62mm_LongPads
U4: FQP27P06; TO-220_Neutral123_Vertical
XA1: Arduino_Mega2560_Shield

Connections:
+5V: P5.8, P6.8, P7.5, P8.4, P15.1, P17.7, R8.1, U3.11 (T1IN), U3.12 (R1OUT), U3.13 (R1IN), U3.14 (T1OUT), U3.16 (VCC), U4.3, XA1.5V1 (5V), XA1.5V3 (5V), XA1.5V4 (5V); also elsewhere on the board
/Logger_part/ANALOG_1: P10.1, XA1.A8
/Logger_part/ANALOG_2: P10.2, XA1.A7
/Logger_part/ANALOG_3: P10.3, XA1.A6
/Logger_part/ANALOG_4: P10.4, XA1.A5
/Logger_part/ANALOG_5: P10.5, XA1.A4
/Logger_part/ANALOG_6: P10.6, XA1.A3
/Logger_part/ANALOG_7: P10.7, XA1.A2
/Logger_part/ANALOG_8: P10.8, XA1.A1
/Logger_part/DGTL_1: P11.1, XA1.D9
/Logger_part/DGTL_2: P11.2, XA1.D8
/Logger_part/DGTL_3: P11.3, XA1.D7
/Logger_part/DGTL_4: P11.4, XA1.D6
/Logger_part/DGTL_5: P11.5, XA1.D5
/Logger_part/DGTL_6: P11.6, XA1.D4
/Logger_part/DGTL_7: P11.7, XA1.D3 (D3_INT1)
/Logger_part/DGTL_8: P11.8, XA1.D2 (D2_INT0)
/Logger_part/IRD_ON_OFF: P7.3, P17.3, XA1.D49
/Logger_part/IRD_RXC: P7.1, P16.5, XA1.D17 (D17_RX2)
/Logger_part/IRD_TXD: P7.2, P16.4, XA1.D16 (D16_TX2)
/Logger_part/MEGA_RX_1: P5.5, XA1.D19 (D19_RX1)
/Logger_part/MEGA_TX_1: P5.6, XA1.D18 (D18_TX1)
/Logger_part/MISO: P6.4, P12.3, XA1.D50
/Logger_part/MOSI: P6.3, P12.2, XA1.D51
/Logger_part/RPI_control: R8.2, U4.1, XA1.D46
/Logger_part/RPI_header/RPI_power_5V: C8.1, P9.1, R9.1, U4.2; also elsewhere on the board
/Logger_part/RX0: P14.2, XA1.D0 (D0_RX0)
/Logger_part/RX3: U3.9 (R2OUT), XA1.D15 (D15_RX3)
/Logger_part/SCK: P6.5, P12.1, XA1.D52
/Logger_part/SCL: P13.1, XA1.SCL
/Logger_part/SDA: P13.2, XA1.SDA
/Logger_part/SS: P6.2, XA1.D53 (D53_SS)
/Logger_part/TX0: P14.1, XA1.D1 (D1_TX0)
/Logger_part/TX3: U3.10 (T2IN), XA1.D14 (D14_TX3)
/Logger_part/VN_WHITE: P8.2, U3.8 (R2IN)
/Logger_part/VN_YELLOW: P8.1, U3.7 (T2OUT)
/Power_part/Batt_plus: XA1.A0; also elsewhere on the board
/Power_part/Feedback_Mega: XA1.D48; also elsewhere on the board
/Power_part/Mega_ground: C3.2, C6.1, C7.1, C8.2, P5.7, P6.6, P7.4, P8.3, P9.2, P15.2, P17.1, R9.2, U3.15 (GND), XA1.GND1 (GND), XA1.GND2 (GND), XA1.GND3 (GND), XA1.GND5 (GND), XA1.GND6 (GND); also elsewhere on the board
unnamed: C3.1, XA1.RST1 (RESET)
unnamed: C4.1, U3.1 (C1+)
unnamed: C4.2, U3.3 (C1-)
unnamed: C5.1, U3.4 (C2+)
unnamed: C5.2, U3.5 (C2-)
unnamed: C6.2, U3.2 (V+)
unnamed: C7.2, U3.6 (V-)

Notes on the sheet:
digital pins
ADC
SPI
I2C
Serial 0 (for RPi)
power

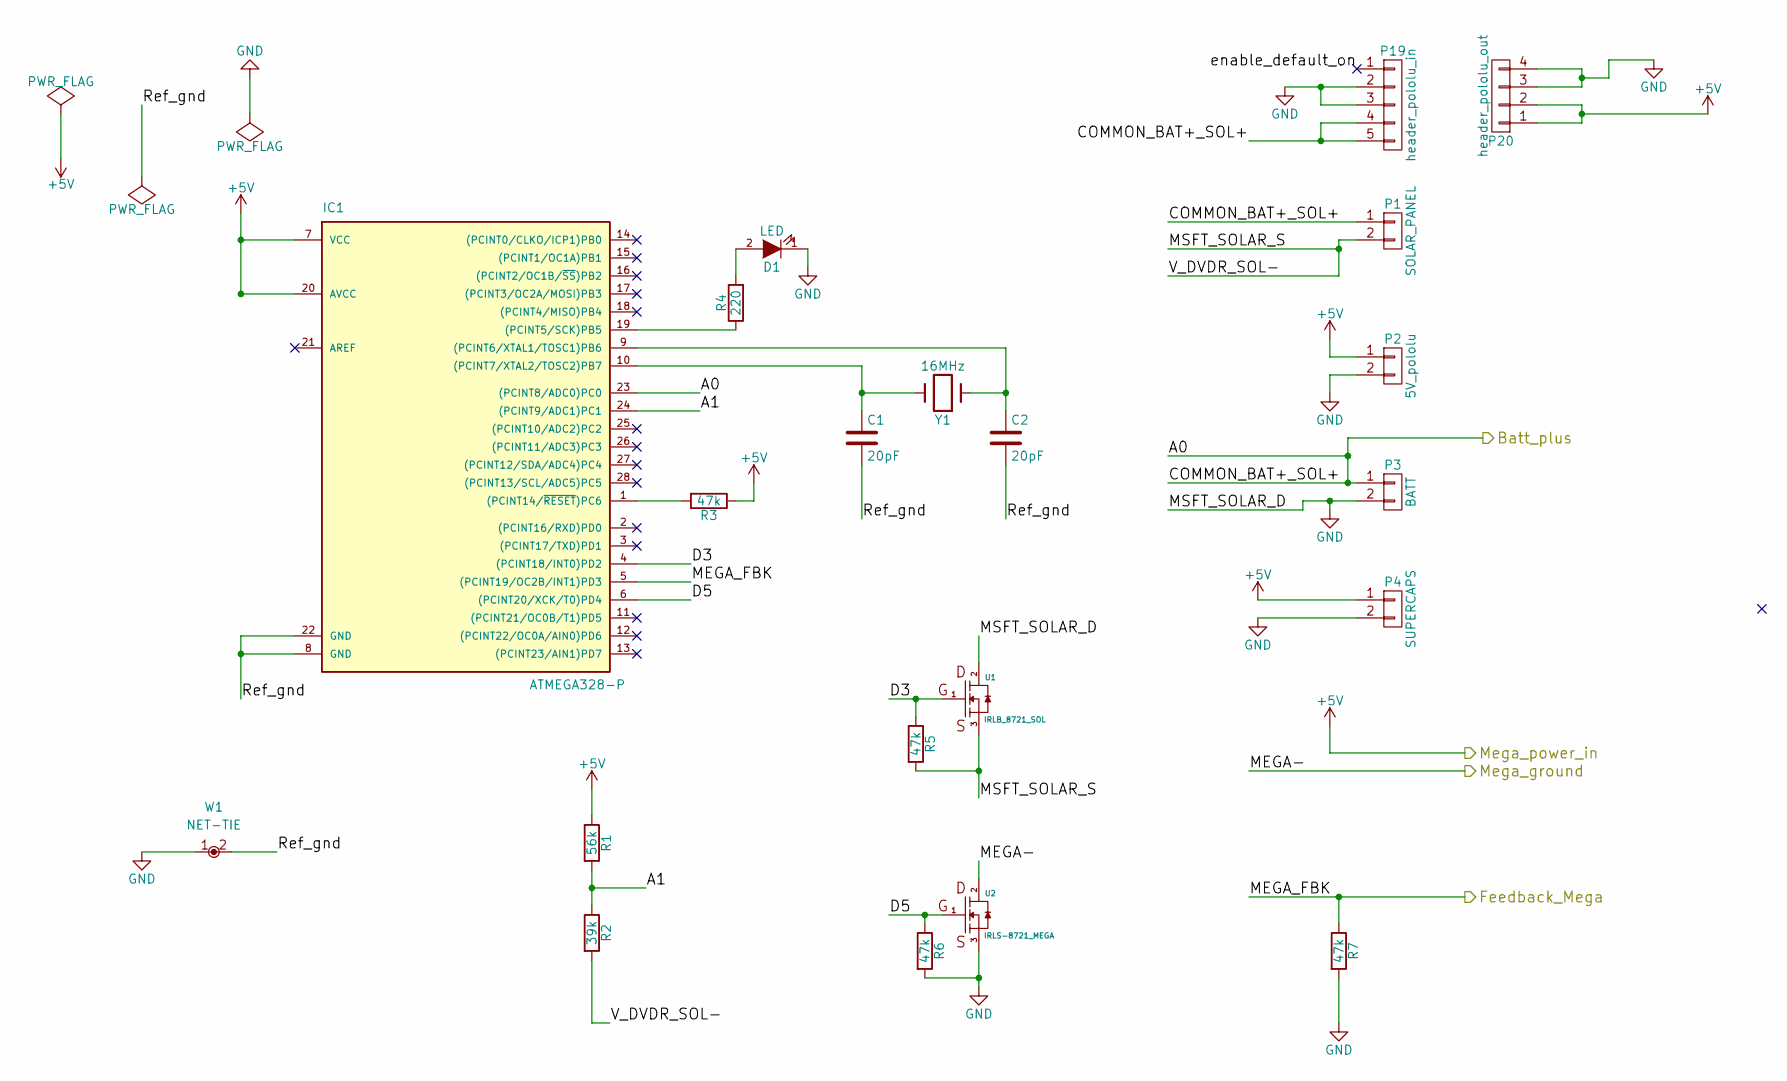
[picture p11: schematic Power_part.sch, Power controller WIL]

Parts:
C1, C2: 20pF; C_Disc_D3_P2.5
D1: LED; LED-3MM
IC1: ATMEGA328-P; DIP-28_W7.62mm_LongPads
P1: SOLAR_PANEL; WireConnection_2.00mmDrill
P2: 5V_pololu; WireConnection_2.00mmDrill
P3: BATT; WireConnection_2.00mmDrill
P4: SUPERCAPS; WireConnection_2.00mmDrill
P19: header_pololu_in; Pin_Header_Straight_1x05
P20: header_pololu_out; Pin_Header_Straight_1x04
R1: 56k; Resistor_Horizontal_RM10mm
R2: 39k; Resistor_Horizontal_RM10mm
R3, R5, R6, R7: 47k; Resistor_Horizontal_RM10mm
R4: 220; Resistor_Horizontal_RM10mm
U1: IRLB_8721_SOL; TO-220_Neutral123_Vertical
U2: IRLS-8721_MEGA; TO-220_Neutral123_Vertical
W1: NET-TIE; NetTie-I_Connected
Y1: 16MHz; Crystal_HC49-U_Vertical

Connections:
+5V: IC1.7 (VCC), IC1.20 (AVCC), P2.1, P4.1, P20.1, P20.2, R1.1, R3.1; also elsewhere on the board
/Power_part/A1: IC1.24 ((PCINT9/ADC1)PC1), R1.2, R2.1
/Power_part/Batt_plus: IC1.23 ((PCINT8/ADC0)PC0), P1.1, P3.1, P19.4, P19.5; also elsewhere on the board
/Power_part/D3: IC1.4 ((PCINT18/INT0)PD2), R5.1, U1.1
/Power_part/D5: IC1.6 ((PCINT20/XCK/T0)PD4), R6.1, U2.1
/Power_part/Feedback_Mega: IC1.5 ((PCINT19/OC2B/INT1)PD3), R7.1; also elsewhere on the board
/Power_part/MSFT_SOLAR_S: P1.2, R2.2, R5.2, U1.3
/Power_part/Mega_ground: U2.2; also elsewhere on the board
/Power_part/Ref_gnd: C1.2, C2.2, IC1.8 (GND), IC1.22 (GND), W1.2
/Power_part/enable_default_on: P19.1
GND: D1.1 (K), P2.2, P3.2, P4.2, P19.2, P19.3, P20.3, P20.4, R6.2, R7.2, U1.2, U2.3, W1.1
unnamed: C1.1, IC1.10 ((PCINT7/XTAL2/TOSC2)PB7), Y1.2
unnamed: C2.1, IC1.9 ((PCINT6/XTAL1/TOSC1)PB6), Y1.1
unnamed: D1.2 (A), R4.2
unnamed: IC1.1 ((PCINT14/~RESET~)PC6), R3.2
unnamed: IC1.19 ((PCINT5/SCK)PB5), R4.1

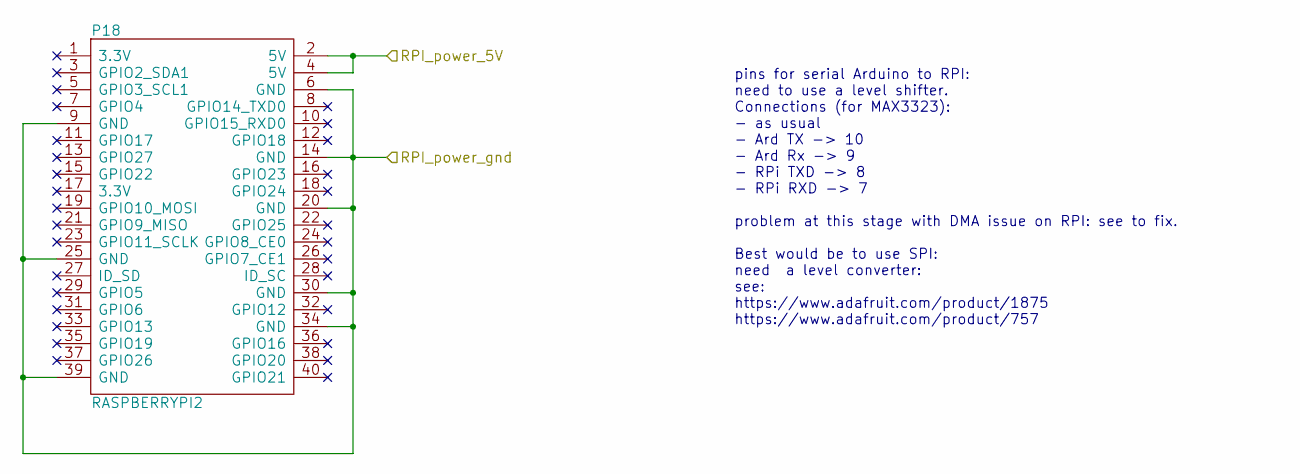
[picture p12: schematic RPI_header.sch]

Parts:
P18: RASPBERRYPI2; Pin_Header_Straight_2x20

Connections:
/Logger_part/RPI_header/RPI_power_5V: P18.2 (5V), P18.4 (5V); also elsewhere on the board
/Power_part/Mega_ground: P18.6 (GND), P18.9 (GND), P18.14 (GND), P18.20 (GND), P18.25 (GND), P18.30 (GND), P18.34 (GND), P18.39 (GND); also elsewhere on the board

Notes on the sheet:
pins for serial Arduino to RPI: need to use a level shifter. Connections (for MAX3323): - as usual - Ard TX -> 10 - Ard Rx -> 9 - RPi TXD -> 8 - RPi RXD -> 7 problem at this stage with DMA issue on RPI: see to fix. Best would be to use SPI: need a level converter: see: https://www.adafruit.com/prod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

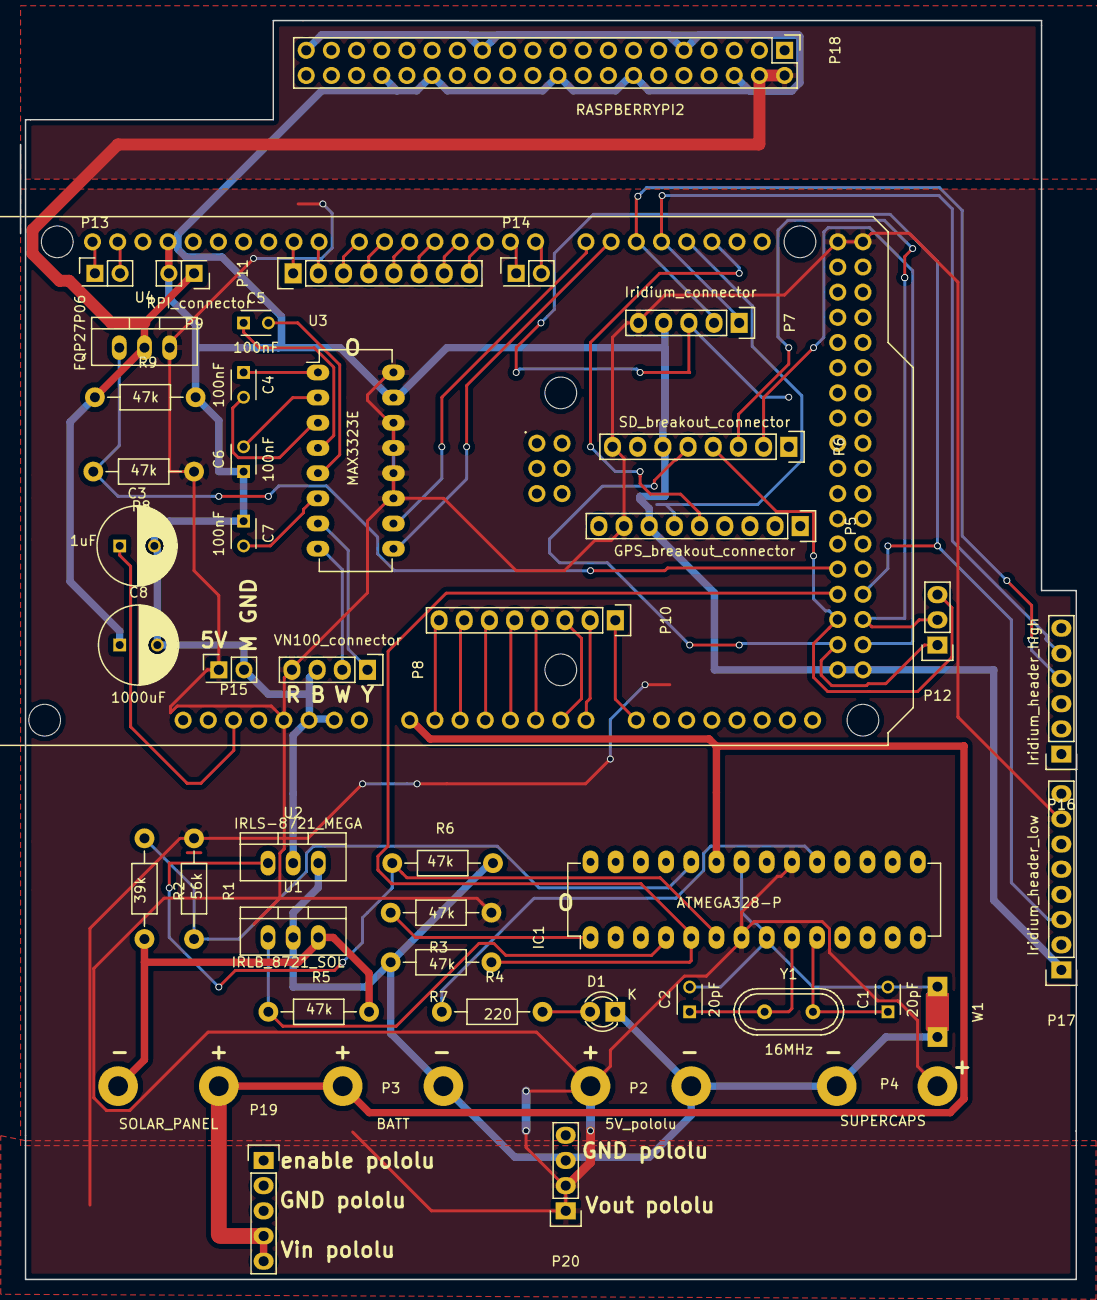
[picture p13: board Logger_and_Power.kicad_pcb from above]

Board: 2 copper layers, 106.0 x 127.0 mm, 46 parts (1 on the bottom side), 57 nets.

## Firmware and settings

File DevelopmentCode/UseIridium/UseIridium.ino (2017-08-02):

/*
   Tests about IdidiumSBD library with the RockBlock7

   Pins

   - RockBlock7        to    Arduino Mega
   - Rockblock7 OnOff  to    49
   - Rockblock7 GND    to    Mega GND
   - Rockblock7 5vIn   to    Mega 5V
   - Rockblock7 TXD    to    Mega TX2
   - Rockblock7 RXD    to    Mega RX2

   This means that the D in RXD and TXD means 'Device', i.e. RX of the device (Mega)
  instead of RX of the host (Rockblock7)

   TODO

   - send vital information by Iridium: battery, GPS, file number
   - receive update information from Iridium
   - send additional processed results

*/




// Iridium module: to add to Mega code %%%%%%%%%%%%%%%%%%%%%%%%%%%%%%%%%%%%%%%%%%
#include "IridiumSBD.h"
#include<stdlib.h>

#define PIN_IRD_SLEEP 49
#define SERIAL_IRIDIUM Serial2

#define PIN_MSR_BATTERY A0
String string_battery = "";

IridiumSBD isbd(SERIAL_IRIDIUM, PIN_IRD_SLEEP);
int signalQuality = 255;

char GPS_rx_buffer[128];
int GPS_rx_buffer_position = 0;

int current_n_read_GPS = 0;

char Iridium_msg[100];
int Iridium_msg_position = 0;

uint8_t Ird_rx[270];
size_t Ird_rx_position = sizeof(Ird_rx);

int ird_feedback = -1;


/////////////////////////////////////////////////////////////////////////////////
/////////////////////////////////////////////////////////////////////////////////
// Defines that are already in the Mega code %%%%%%%%%%%%%%%%%%%%%%%%%%%%%%%%%%%%
#define SERIAL_PRINT true

#include <Adafruit_GPS.h>
// note: we do not use software serial but it seems to be necessary for initializing
// Adafruit_GPS library
#include <SoftwareSerial.h>
#include <avr/wdt.h>

// GPS
// config GPS chip and instance creation
#define SERIAL_GPS Serial1
Adafruit_GPS GPS(&SERIAL_GPS);
// GPS string
String dataStringGPS = "";

char currentFileName[] = "F12345";
// number of zeros after the letter in the name convention
int nbrOfZeros = 5;
/////////////////////////////////////////////////////////////////////////////////
/////////////////////////////////////////////////////////////////////////////////

// %%%%%%%%%%%%%%%%%%%%%%%%%%%%%%%%%%%%%%%%%%%%%%%%%%%%%%%%%%%%%%%%%%%%%%%%%%%%%%
void setup() {
  delay(5000);

  // Start the serial port for debugging
#if SERIAL_PRINT
  Serial.begin(115200);
  Serial.println("-- Starting Serial");
#endif

  // setup GPS
  delay(250);

  // 9600 NMEA is the default baud rate for Adafruit MTK GPS's- some use 4800
  GPS.begin(9600);

  // uncomment this line to turn on RMC (recommended minimum) and GGA (fix data) including altitude
  GPS.sendCommand(PMTK_SET_NMEA_OUTPUT_RMCGGA);
  // uncomment this line to turn on only the "minimum recommended" data
  // GPS.sendCommand(PMTK_SET_NMEA_OUTPUT_RMCONLY);

  // Set the update rate
  GPS.sendCommand(PMTK_SET_NMEA_UPDATE_1HZ);   // 1 Hz update rate
  GPS.sendCommand(PMTK_API_SET_FIX_CTL_1HZ);
  // For the parsing code to work nicely and have time to sort thru the data, and
  // print it out we don't suggest using anything higher than 1 Hz

  // Request updates on antenna status, comment out to keep quiet
  // GPS.sendCommand(PGCMD_ANTENNA);

  delay(1000);

  // Ask for firmware version
  // SERIAL_GPS.println(PMTK_Q_RELEASE);

#if SERIAL_PRINT
  Serial.println("D;GPS initialized");
#endif

  // Iridium setup %%%%%%%%%%%%%%%%%%%%%%%%%%%%%%%%%%%%%%%%%%%%%%%%%%%%%%%%%%%%
#if SERIAL_PRINT
  Serial.println("D;Starting Iridium SBD object");
#endif

  SERIAL_IRIDIUM.begin(19200);

#if SERIAL_PRINT
  Serial.println("D;Serial to Iridium SBD");
  isbd.attachConsole(Serial);
  isbd.attachDiags(Serial);
#endif

#if SERIAL_PRINT
  Serial.println("D;Iridium power profile");
#endif

  // set power profile
  // 0 when high power supply
  // 1 when low power supply
  isbd.setPowerProfile(0);

#if SERIAL_PRINT
  Serial.println("D;Iridium begin method");
#endif

  // Wake up and prepare to communicate
  isbd.begin();

  // sleep and wake up example:
  /*
    isbd.sleep();
    delay(5000);
    isbd.begin();
  */



  wdt_enable(WDTO_8S);
  wdt_reset();
}

// %%%%%%%%%%%%%%%%%%%%%%%%%%%%%%%%%%%%%%%%%%%%%%%%%%%%%%%%%%%%%%%%%%%%%%%%%%%%%%
void loop() {

  while (1){

    wdt_reset();
    
    if (Serial.available() > 0){
      char c_read;
      c_read = Serial.read();
      if (c_read == 'T'){
        break;
      }
    }
  }

  wdt_reset();

  // get the Iridium feedback string ready
  set_battery_value_Iridium_message();

  set_file_number_Iridium_message();

  obtain_GPRMC_Iridium_message();
  set_GPRMC_Iridium_message();

  #if SERIAL_PRINT
    Serial.println((uint8_t)Iridium_msg);
  #endif

  // try to send the Iridium feedback string
  // note: retries the operation for up to 300 seconds by default; put watchdog reset in
  // ISBDCallback.
  ird_feedback = isbd.sendReceiveSBDBinary((uint8_t *)Iridium_msg, size_t(1 + GPS_rx_buffer_position),
                                           Ird_rx, Ird_rx_position);

  #if SERIAL_PRINT
    if (ird_feedback != 0){
      Serial.print("D;Problem transmitting: ");
      Serial.println(ird_feedback);
    }
    else{
      Serial.println("D;Transmitted well");
    }
  #endif

  wdt_reset();

  //////////////////////////////////////////////////////////////////////////////////////
  //////////////////////////////////////////////////////////////////////////////////////

  // read Iridium command if available, as many times as incoming messages
  do{
      #if SERIAL_PRINT
        Serial.print("Inbound buffer size is ");
        Serial.println(Ird_rx_position);
        for (int i=0; i<Ird_rx_position; ++i){
          Serial.write(Ird_rx[i]);
          Serial.print("(");
          Serial.print(Ird_rx[i]);
          Serial.print(") ");
        }
        Serial.print("Messages left: ");
        Serial.println(isbd.getWaitingMessageCount());
      #endif
  
    wdt_reset();
  
    // use do...while to go through all messages
    // check also commands to RPi
  
    // check if command back
    if (Ird_rx_position > 0){
      #if SERIAL_PRINT
        Serial.print(F("Ird_rx_position > 0: "));
        Serial.println(Ird_rx_position);
      #endif
  
      // check if should update number of sleep cycles
      // this kind of message should be of the form: SLP12 [set the number of sleep cycles
      // to 12]
      if (char(Ird_rx[0]) == 'S' && char(Ird_rx[1]) == 'L' && char(Ird_rx[2]) == 'P'){
         int value_sleep = uint8_t(Ird_rx[3]);
  
        #if SERIAL_PRINT
          Serial.print(F("Will sleep for:"));
          Serial.println(value_sleep);
        #endif
      }
  
      // check if should send some commands to RPi
    }

    // if more messages to get, use more sendReceive
    if (isbd.getWaitingMessageCount() > 0){
      
      #if SERIAL_PRINT
        Serial.println(F("D;Receive one more message"));
      #endif
      
      Ird_rx_position = sizeof(Ird_rx);
      ird_feedback = isbd.sendReceiveSBDBinary(NULL, 0, Ird_rx, Ird_rx_position);
      
    }
    else{
      
      #if SERIAL_PRINT
        Serial.println(F("D;No more messages"));
      #endif
      
      break;
      
    }
    
  }while(true);
  //////////////////////////////////////////////////////////////////////////////////////
  //////////////////////////////////////////////////////////////////////////////////////
}

/*
 * GOT ANSWER IN CONSOLE:
 * 
D;Transmitted well
Inbound buffer size is 5
T(84) e(101) s(115) t(116) 1(49) Messages left: 0
 *
 */

// %%%%%%%%%%%%%%%%%%%%%%%%%%%%%%%%%%%%%%%%%%%%%%%%%%%%%%%%%%%%%%%%%%%%%%%%%%%%
// Put the battery value reading in the Iridium message
// %%%%%%%%%%%%%%%%%%%%%%%%%%%%%%%%%%%%%%%%%%%%%%%%%%%%%%%%%%%%%%%%%%%%%%%%%%%%
void set_battery_value_Iridium_message(void){
  // measure battery
  string_battery = String(analogRead(PIN_MSR_BATTERY), DEC);

  #if SERIAL_PRINT
    Serial.println(F("D;Battery reading"));
    Serial.print("D;");
    Serial.print(string_battery[0]);
    Serial.print(string_battery[1]);
    Serial.println(string_battery[2]);
  #endif

  Iridium_msg[0] = string_battery[0];
  Iridium_msg[1] = string_battery[1];
  Iridium_msg[2] = string_battery[2];
}

// %%%%%%%%%%%%%%%%%%%%%%%%%%%%%%%%%%%%%%%%%%%%%%%%%%%%%%%%%%%%%%%%%%%%%%%%%%%%
// Put the file number in the Iridium message
// %%%%%%%%%%%%%%%%%%%%%%%%%%%%%%%%%%%%%%%%%%%%%%%%%%%%%%%%%%%%%%%%%%%%%%%%%%%%
void set_file_number_Iridium_message(void){
  // get file number

  #if SERIAL_PRINT
    Serial.println(F("D;File number"));
    Serial.print("D;");
    for (int i = 1; i < nbrOfZeros + 1; i++) {
      Serial.print(currentFileName[i]);
    }
    Serial.println();
  #endif

  Iridium_msg[3] = currentFileName[1];
  Iridium_msg[4] = currentFileName[2];
  Iridium_msg[5] = currentFileName[3];
  Iridium_msg[6] = currentFileName[4];
  Iridium_msg[7] = currentFileName[5];
}

// %%%%%%%%%%%%%%%%%%%%%%%%%%%%%%%%%%%%%%%%%%%%%%%%%%%%%%%%%%%%%%%%%%%%%%%%%%%%
// Obtain a GPS GPRMC string to be used in the Iridium message
// %%%%%%%%%%%%%%%%%%%%%%%%%%%%%%%%%%%%%%%%%%%%%%%%%%%%%%%%%%%%%%%%%%%%%%%%%%%%
void obtain_GPRMC_Iridium_message(void){
  
  // flush GPS buffer
  while (SERIAL_GPS.available() > 0) {
    SERIAL_GPS.read();
  }

  // variable for holding GPS chars
  char c_GPS = '0';

  // try to read at most 10 GPS strings; if no valid GPRMC strings
  // 10 times in a row, just use the last one
  while (current_n_read_GPS < 10) {

    wdt_reset();

    // if this is the beginning of a new GPS message, log it,
    // check if GPRMC and check if valid
    if (c_GPS == '\n') {

      #if SERIAL_PRINT
        Serial.print(F("D;Attempt reading GPS number: "));
        Serial.println(current_n_read_GPS);
      #endif

      // init buffer position
      GPS_rx_buffer_position = 0;

      bool end_GPS_msg = false;

      // log the whole message
      while (!end_GPS_msg) {
        if (SERIAL_GPS.available() > 0) {

          c_GPS = GPS.read();

          if (c_GPS == '\n') {
            end_GPS_msg = true;
          }

          else {
            GPS_rx_buffer[GPS_rx_buffer_position] = c_GPS;
            GPS_rx_buffer_position++;
          }
        }
      }

      #if SERIAL_PRINT
        Serial.print(F("D;Read:"));
        for (int i = 0; i < GPS_rx_buffer_position; i++) {
          Serial.print(GPS_rx_buffer[i]);
        }
        Serial.println();
      #endif

      // check if the logged message was GPRMC
      if ((GPS_rx_buffer[0] == '$') && (GPS_rx_buffer[1] == 'G') && (GPS_rx_buffer[2] == 'P') &&
          (GPS_rx_buffer[3] == 'R') && (GPS_rx_buffer[4] == 'M') && (GPS_rx_buffer[5] == 'C')) {

      #if SERIAL_PRINT
          Serial.println("D;GPRMC");
      #endif

        current_n_read_GPS++;
      }

      // check if valid fix; if it is the case, finish here
      if (GPS_rx_buffer[18] == 'A') {
      #if SERIAL_PRINT
          Serial.println("D;Valid");
      #endif

        break;
      }

    }
    // if GPS logging started at the middle of a string,
    // wait for the end of next message
    else if (SERIAL_GPS.available() > 0) {
            c_GPS = GPS.read();
    }

  }
}

// %%%%%%%%%%%%%%%%%%%%%%%%%%%%%%%%%%%%%%%%%%%%%%%%%%%%%%%%%%%%%%%%%%%%%%%%%%%%
// Set the GPS GPRMC string in the Iridium message
// %%%%%%%%%%%%%%%%%%%%%%%%%%%%%%%%%%%%%%%%%%%%%%%%%%%%%%%%%%%%%%%%%%%%%%%%%%%%
void set_GPRMC_Iridium_message(void){
  #if SERIAL_PRINT
    Serial.println(F("GPRMC message to use:"));
    for (int i = 0; i < GPS_rx_buffer_position; i++) {
      Serial.print(GPS_rx_buffer[i]);
    }
    Serial.println();
  #endif

  // add the GPS information into the message string
  for (int i = 0; i < GPS_rx_buffer_position - 7; i++) {
    Iridium_msg[8 + i] = GPS_rx_buffer[i + 7];
  }

  #if SERIAL_PRINT
    Serial.print(F("Iridum_msg length:"));
    Serial.println(GPS_rx_buffer_position + 1);
    for (int i = 0; i < 1 + GPS_rx_buffer_position; i++) {
      Serial.print(Iridium_msg[i]);
    }
    Serial.println();
  #endif
}

bool ISBDCallback(void){
  wdt_reset();
  return(true);
}

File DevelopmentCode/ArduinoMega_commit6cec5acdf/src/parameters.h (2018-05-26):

/*

Copyright (c) 2015 Jean Rabault jean.rblt@gmail.com

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
*/

/*
  crucial for good functionning:
    - check DEBUG parameter: should be false for use with RPi, otherwise will not work!!
    - check USE_IRIDIUM: should be true for use of real iridium and not dummy; false will be dummy iridium
    - check DURATION_LOGGING_MS
    - check MAX_NBR_SLEEPS_BEFORE_WAKEUP
*/

#ifndef PARAMETERS_LOGGER_MEGA
#define PARAMETERS_LOGGER_MEGA

#define DELAY_START_SERIAL 20

#define PIN_MSR_BATTERY A0
#define BAT_EMPTY_V 2.8     // threshold for empty battery

// Debug
#define DEBUG false
#define SERIAL_DEBUG Serial
#define SERIAL_DEBUG_BAUDRATE 115200

// SD
#define PIN_SELECT_SD 53
#define NBR_ZEROS_FILENAME 5

// GPS
#define SERIAL_GPS Serial1
#define SIZE_GPS_BUFFER 128
#define MAX_NUMBER_ATTEMPTS_GPRMC 20  // GPS works at 1Hz

// constraints on max number of sleep cycles between wakeups
#define MAX_NBR_SLEEPS_BEFORE_WAKEUP 18
// #define MAX_NBR_SLEEPS_BEFORE_WAKEUP 1

// Iridium
#define IRIDIUM_TRANSMIT_PACKET_SIZE 340
#define IRIDIUM_RECEIVED_PACKET_SIZE 270
#define USE_IRIDIUM true
#define PIN_IRD_SLEEP 49
#define SERIAL_IRIDIUM Serial2
#define IRIDIUM_LOW_POWER_SUPPLY 1
#define IRIDIUM_HIGH_POWER_SUPPLY 0
#define NBR_SIGNIFICANT_DIGITS_BATT_LEVEL 2

// Raspberry
#define PIN_MFT_RPI 46
#define SERIAL_RASPBERRY Serial
#define DELAY_ANSWER_RPI 500
#define TIMEOUT_ACKNOWLEDGEMENT_RPI_MS 4000UL
#define TIMEOUT_PROCESSING_RPI 60000UL
#define TIMEOUT_WAKEUP_RPI 120000UL
#define TIMEOUT_RECEIVED_TO_TRANSMIT_FROM_PI 60000UL

// VN 100
#define SERIAL_VN100 Serial3
#define SIZE_BUFFER_VN100 256

// feedback mega pin: high as long as the Mega should get power
#define PIN_FBK_MGA 48

// how long should log
// #define DURATION_LOGGING_MS 1800000UL  // initially
#define DURATION_LOGGING_MS 1500000UL  // should be enough
// #define DURATION_LOGGING_MS 30000UL  // for tests

// LED
#define PIN_MGA_LED 13

// EEPROM
#define ADDRESS_LONG_FILENBR 1  // address for the filenumber; takes 4 bytes
#define ADDRESS_SLEEPS_LEFT 5  // address for where number of sleep cycles left stored
#define ADDRESS_TOTAL_NBR_SLEEPS 6  // address for what is the total number of sleep cycles

#endif

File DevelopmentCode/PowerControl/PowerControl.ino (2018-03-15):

/*
 * Code for power control
 *
 * This code takes care of the power management, and should be uploaded on the barebone ATMega328P
 *
 * Its functions are to:
 *
 * - Sleep most of the time in lowest power mode, but watchdog wake up at regular intervals
 *
 * - Take care of the battery and solar panel. Each time it wakes up, check if the battery and solar panel should be connected
 *
 * - Take care of the power to the Arduino Mega. Each time it wakes up, check what should be the next state of the Arduino Mega.
 *
 * - The parameters are set in the parameters.h header file
 *
 * TODO:
 * 
 * - Possible optimization (require hardware update; overkill and probably over engineering)
 * put the pololu on a MOSFET from the battery side (to disconnect it when not needed, ie when not using
 * the Mega). Then need to be sure voltage on capacitors do not get too low: re connect pololu when logging with
 * Mega, and connect at least 8 seconds each 15 minutes [note: check values].
 *

 Copyright (c) 2015 Jean Rabault jean.rblt@gmail.com

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
 */

#include "sleep_and_watchdog.h"
#include "client_device.h"
#include "solar_controller.h"
#include "parameters.h"

SleepWatchdog sleep_watchdog_instance{};
BatteryController battery_controller_instance{PIN_MSR_BAT, &sleep_watchdog_instance};
CDV mega_device{PIN_FBK_MGA, PIN_MFT_MGA, CYCLES_BEFORE_MEGA_WAKEUP, &battery_controller_instance};
SolarController solar_controller_instance{PIN_MFT_SOL, PIN_MSR_SOL, &battery_controller_instance};

// %%%%%%%%%%%%%%%%%%%%%%%%%%%%%%%%%%%%%%%%%%%%%%%%%%%%%%%%%%%%%%%%%%%%%%%%%%%%%%
// %%%%%%%%%%%%%%%%%%%%%%%%%%%%%%%%%%%%%%%%%%%%%%%%%%%%%%%%%%%%%%%%%%%%%%%%%%%%%%
void setup() {

  #if DEBUG
    Serial.begin(115200);
    delay(500);
  #endif

  // --------------------------------------------------------------
  // Configure watchdog
  // --------------------------------------------------------------

  sleep_watchdog_instance.configure_wdt();
  wdt_reset();

  // --------------------------------------------------------------
  // Prepare pins
  // --------------------------------------------------------------

  // set the mode of the digital pins (analog pins do not need to be set)
  pinMode(PIN_FBK_MGA, INPUT);
  pinMode(PIN_MFT_SOL, INPUT);
  pinMode(PIN_MFT_MGA, INPUT);

  // --------------------------------------------------------------
  // first battery measurement
  // --------------------------------------------------------------
  battery_controller_instance.update();

}
// %%%%%%%%%%%%%%%%%%%%%%%%%%%%%%%%%%%%%%%%%%%%%%%%%%%%%%%%%%%%%%%%%%%%%%%%%%%%%%
// %%%%%%%%%%%%%%%%%%%%%%%%%%%%%%%%%%%%%%%%%%%%%%%%%%%%%%%%%%%%%%%%%%%%%%%%%%%%%%

// %%%%%%%%%%%%%%%%%%%%%%%%%%%%%%%%%%%%%%%%%%%%%%%%%%%%%%%%%%%%%%%%%%%%%%%%%%%%%%
// %%%%%%%%%%%%%%%%%%%%%%%%%%%%%%%%%%%%%%%%%%%%%%%%%%%%%%%%%%%%%%%%%%%%%%%%%%%%%%
void loop() {

  #if DEBUG
    Serial.println(F("--- loop ---"));
    delay(10);
  #endif

  // --------------------------------------------------------------
  // Start a new cycle: let the time to wake up
  // --------------------------------------------------------------

  delay(5);

  // --------------------------------------------------------------
  // measure battery
  // --------------------------------------------------------------

  battery_controller_instance.update();

  wdt_reset();

  // --------------------------------------------------------------
  // Decide what should do with the solar panel
  // --------------------------------------------------------------

  solar_controller_instance.update_panel_status();

  wdt_reset();

  // --------------------------------------------------------------
  // Decide what to do with the Arduino Mega
  // --------------------------------------------------------------

  mega_device.update_status();

  wdt_reset();

  // --------------------------------------------------------------
  // Sleep
  // --------------------------------------------------------------

  #if DEBUG
    Serial.println(F("go to sleep..."));
    delay(10);
  #endif

  
  sleep_watchdog_instance.sleep(CYCLES_DEEP_SLEEP);
}
// %%%%%%%%%%%%%%%%%%%%%%%%%%%%%%%%%%%%%%%%%%%%%%%%%%%%%%%%%%%%%%%%%%%%%%%%%%%%%%
// %%%%%%%%%%%%%%%%%%%%%%%%%%%%%%%%%%%%%%%%%%%%%%%%%%%%%%%%%%%%%%%%%%%%%%%%%%%%%%

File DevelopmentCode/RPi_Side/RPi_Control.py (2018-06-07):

from __future__ import print_function
import serial
import glob
from printind.printind_function import printi
from parser_logger import Parser_logger
from compute_statistics import WaveStatistics
from time import sleep
import os
from analyze_stream import AnalyzeStream
from time import time

"""
TODO: add a manager that erases old files, to avoid filling the memory
TODO: do not tranmit reduced spectrum if no signal
TODO: test processing and sending back through Iridium together with the Mega
TODO: command for sending back whole parts of a file (TRT command)
NOTE: may need to help the Arduino for transmitting through the Iridium by cutting the file in different parts to accomodate
Iridium buffer size.
"""


class RPi_control(object):
    def __init__(self, verbose=0, main_path='/home/pi/Logger/', debug=False):
        self.verbose = verbose
        self.main_path = main_path
        self.debug = debug

    def open_serial_to_arduino(self):
        '''Find available serial ports to Arduino
        '''
        available_ports = glob.glob('/dev/ttyACM*')
        self.serial_port = serial.Serial(available_ports[0], baudrate=115200)
        self.serial_port.flushInput()
        self.serial_port.flushOutput()

        if self.verbose > 0:
            printi('Using port: ' + str(available_ports[0]))

    def connect_to_Arduino(self):
        """Connect to the Arduino: acknowledge that listening."""

        wait_for_acknowledged_connection = True

        # clear the incoming buffer except last received char
        while self.serial_port.in_waiting > 1:
            self.serial_port.read()

        # look at last received char
        while wait_for_acknowledged_connection:
            if self.serial_port.in_waiting > 0:
                crrt_char = self.serial_port.read()

                if self.verbose > 5:
                    printi('Received char: ' + str(crrt_char))

                if crrt_char == 'B':
                    self.serial_port.write('R')

                wait_for_acknowledged_connection = False

        if self.verbose > 5:
            printi("Connection Acknowledged")

    def receive_from_Arduino(self):

        self.list_of_commands = ['DEFAULT']
        self.filename = ""
        self.data = ""

        # received commands ----------------------------------------------------
        if self.verbose > 0:
            printi("Receive commands")

        wait_for_commands = True
        current_command = []

        while wait_for_commands:
            if self.serial_port.in_waiting > 0:
                crrt_char = self.serial_port.read()

                if self.verbose > 5:
                    printi('Received char: ' + str(crrt_char))

                if crrt_char == 'C':
                    self.list_of_commands.append(''.join(current_command))
                    current_command = []

                elif crrt_char == 'N':
                    self.list_of_commands.append(''.join(current_command))
                    wait_for_commands = False

                else:
                    current_command.append(crrt_char)

        # receive filename ----------------------------------------------------
        if self.verbose > 5:
            printi("Receive Filename")

        self.serial_port.write('N')

        wait_for_filename = True
        filename_list = []

        while wait_for_filename:
            if self.serial_port.in_waiting > 0:
                crrt_char = self.serial_port.read()

                if self.verbose > 5:
                    printi('Received char: ' + str(crrt_char))

                if crrt_char == 'N':
                    wait_for_filename = False
                    self.serial_port.write('N')

                else:
                    filename_list.append(crrt_char)

        self.filename = ''.join(filename_list)

        if self.verbose > 0:
            print("filename received: " + self.filename)

        # receive data ---------------------------------------------------------
        if self.verbose > 0:
            printi("Receive data")

        data_list = []
        message_start = "START_TRANSMIT_FILE"
        message_end = "END_TRANSMIT_FILE"

        # receive the start message
        analyze_stream = AnalyzeStream(message_start)

        while not analyze_stream.has_found_message():
            if self.serial_port.in_waiting > 0:
                crrt_char = self.serial_port.read()
                analyze_stream.read_char(crrt_char)

        if self.verbose > 0:
            print("received " + message_start)

        time_start = time()

        # receive the data including the end message
        analyze_stream = AnalyzeStream(message_end)

        while not analyze_stream.has_found_message():
            """
            if self.serial_port.in_waiting > 0:
                crrt_char = self.serial_port.read()
                data_list.append(crrt_char)
                analyze_stream.read_char(crrt_char)
            """

            number_bytes_available = self.serial_port.in_waiting

            if number_bytes_available > 0:

                crrt_char = self.serial_port.read()
                data_list.append(crrt_char)
                analyze_stream.read_char(crrt_char)

            if number_bytes_available < 32:

                self.serial_port.write("O")

        if self.verbose > 0:
            print("received " + message_end)
            print("time elapsed (s): {}".format(time() - time_start))

        # generate the data, taking away end message
        self.data = ''.join(data_list[:-len(message_end)])

    def save_all(self):
        """Save received commands and data, and append the filename list."""

        if self.verbose > 0:
            printi("Append filename_list.txt")

        with open(self.main_path + 'filename_list.txt', "a") as myfile:
            myfile.write(self.filename)
            myfile.write('\n')
            myfile.write("\n")

        if self.verbose > 0:
            printi("Add entry in Commands")

        with open(self.main_path + 'Commands/' + self.filename, "w") as myfile:
            for current_command in self.list_of_commands:
                myfile.write(current_command)
                myfile.write('\n')

        if self.verbose > 0:
            printi("Add entry in Data")

        with open(self.main_path + 'Data/' + self.filename, "w") as myfile:
            myfile.write(self.data)

    def confirm_finished(self):
        """Confirm to Arduino Mega that done with RPi and can be shut down."""

        self.serial_port.write('F')

    def processing(self):
        """Launch the processing of data"""

        # NOTE: can be some problems with paths here...

        # do the parsing of the file from the Mega -----------------------------
        path_in = self.main_path + '/Data/'
        path_out_logger = self.main_path + '/ResultAnalyzis/'
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

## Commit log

2017-07-25 working PowerControl_FromScratch reading voltage panel and battery
2017-07-25 working solar power control with mega feedback and sleep; need to optimize sleeP (?)
2017-07-26 added LED visual feedback
2017-07-27 added png material about power control system
2017-07-27 working on Arduino Mega logger
2017-07-27 thinking about how to add Iridium and RaspberryPi
2017-07-28 added low battery threshold in PowerControl
2017-07-28 should have fixed the when mega up issue
    [PowerControl.ino]
2017-07-28 done for today; logger test with older version of code (from before lunch) working ok but mega sleeping one too many cycle; should be fixed in present code
    [PowerControl.ino]
2017-08-01 added sending of Iridium vital sign to ArduinoMega
2017-08-02 added Iridium feedback to Arduino Mega code; should set number of sleeps as EEPROM variable
2017-08-03 updated Arduino Mega with RPI interaction; added script to be put in RPI crontab
2017-08-03 corrected error in RPi_Control; added Iridium guards in Mega code
    [RPi_Control.py]
2017-08-03 corrected a mistake in the ArduinoMega code (delay that forced 0 in MGA_FBK and Mega shutdown
    [PowerControl.ino, RPi_Control.py]
2017-08-04 completed CHECKLIST: Arduino Mega EEPROM must be initialized with the right number of sleeps
2017-08-04 power working with no LED
2017-08-04 had forgotten to confirm on the RPi side when finished, added now; the bugs were due to Mega reset on opening of serial, not code
    [InitializeEEPROM.ino, PowerControl.ino, RPi_Control.py]
2017-11-27 working on KiCAD
    [power_controller.kicad_pcb, power_controller.sch]
2017-11-28 first version of power controller
    [power_controller.dsn, power_controller.kicad_pcb, power_controller.sch]
2017-11-28 some stupid changes
    [power_controller.kicad_pcb]
2017-11-28 correct new PSB with net-tie on master
    [power_controller.kicad_pcb, power_controller.sch]
2017-11-29 files to send to Olav for double checking
    [power_controller-B.CrtYd.gbr, power_controller-B.Cu.gbl, power_controller-B.Fab.gbr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]
2017-11-30 added pdf prints for Olav
    [power_controller.kicad_pcb]
2017-12-12 v2 with DIL ATMega
    [power_controller-B.CrtYd.gbr, power_controller-B.Cu.gbl, power_controller-B.Fab.gbr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]
2017-12-12 board v3 seems ok
    [power_controller_SMD.csv, power_controller_SMD.kicad_pcb, power_controller_SMD.sch]
2017-12-12 ready to generate first gerbers for test for power manager v3
    [power_controller_SMD.csv, power_controller_SMD.kicad_pcb, power_controller_SMD.sch]
2018-02-09 updated list components prototype
    [power_controller.csv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]
2018-02-21 updated comments and code in sleeping code of power controller
2018-02-21 cleaned / re commented the power manager code
2018-02-23 switched to mega device through CDV class
2018-02-23 cleaned the code for power manager
2018-02-23 ready for test of clean power manager
2018-02-27 compiling with battery controller class
2018-02-28 moving ArduinoMega to Platformio
2018-02-28 remains to implement: VN100 and RaspberryPi interaction
2018-03-01 try to upload; not working yet
    [parameters.h]
2018-03-01 corrected a mistake in sd manager
    [parameters.h, src.ino]
2018-03-01 fixed compatibility bug with how VN100 data was posted for old parser to work
    [BoardManager.cpp, IridiumManager.cpp, parameters.h]
2018-03-06 updating sd manager to support several types of files on Arduino SD card
2018-03-07 working on RaspberryManager
2018-03-12 RaspberryPi control code compiling
2018-03-12 problem in receiving from RPi
    [IridiumSBD.h]
2018-03-12 corrected some format issues
    [RPi_Control.py, compute_statistics.py]
2018-03-13 fixed problem with bad data lines
    [parameters.h]
2018-03-13 probably a problem of watchdog reset when receiving data from RPi; should be corrected now
    [RPi_Control.py, compute_statistics.py, parameters.h]
2018-03-13 was using wrong pin to power RPi on; corrected
    [BoardManager.cpp, src.ino]
2018-03-14 set use iridium, corrected preprocessor typo
    [IridiumManager.cpp, parameters.h]
2018-03-14 fixed problem with power manager
    [PowerControl.ino, battery_controller.cpp, parameters.h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]
2018-03-15 read data line by line. Shortens array if less than 24 minutes
    [compute_statistics.py]
2018-03-15 power controller should be ready for release
2018-03-16 corrected small mistake on duration of sleep in power manager
    [client_device.cpp]
2018-05-04 working on kicad logger
    [Logger.csv, Logger.kicad_pcb, Logger.sch]
2018-05-09 schematic logger seems ok
    [Logger.sch]
2018-05-09 placed components 1
    [Logger.kicad_pcb, Logger.sch, _saved_Logger.sch]
2018-05-09 wired board ok
    [Logger.dsn]
2018-05-09 corrected error on MAX232
    [Logger.kicad_pcb, Logger.sch, _saved_Logger.sch]
2018-05-09 drc warning but should be ok
    [Logger.kicad_pcb]
2018-05-09 extended slightly the board
    [Logger.kicad_pcb]
2018-05-11 fixed interpolation for downsampling spectrum
    [compute_statistics.py]
2018-05-11 ordered first prototype logger shield
    [Logger-B.Cu.gbl, Logger-B.Mask.gbs, Logger-B.SilkS.gbo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]
2018-05-16 updated data analysis code with directional spectrum and automated some part of paths
    [_saved_Logger.sch]
2018-05-24 ready to make some tests with the new logger board
2018-05-26 working on the PCB
    [Logger_and_Power.kicad_pcb, Logger_and_Power.sch, Logger_part.sch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]
2018-05-26 routed ok
    [Logger_and_Power.kicad_pcb]
2018-05-26 all working; problem was being put in spam
    [parameters.h]
2018-05-26 improved 5V plane
    [Logger_and_Power.kicad_pcb]
2018-05-28 ready to try to shift the power controller
    [Logger_and_Power.kicad_pcb, Logger_part.sch, Power_part.sch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]
2018-05-28 moved more space for power controller
    [Logger_and_Power.kicad_pcb]
2018-05-28 retablished 512bytes rx buffers; new PCB with logger and power and headers
    [Logger_and_Power-B.Cu.gbl, Logger_and_Power-B.Mask.gbs, Logger_and_Power-B.SilkS.gbo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]
2018-05-28 corrected shape of the board; added missing wire
    [Logger_and_Power-B.Cu.gbl, Logger_and_Power-B.Mask.gbs, Logger_and_Power-B.SilkS.gbo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]
2018-06-07 fixed an issue in the raspberry pi control on the RPi
    [RPi_Control.py]
2019-05-23 added simple BOM
    [layout_no_wiring.csv]
2019-07-30 now pololu on PCB; need to export gerbers still
    [Logger_and_Power.kicad_pcb, Logger_part.sch, Power_part.sch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]
2019-07-30 PCB with pololu support, for order 07-2019
    [Logger_and_Power-B.Cu.gbl, Logger_and_Power-B.Mask.gbs, Logger_and_Power-B.SilkS.gbo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]
2019-10-07 just commit to work further
    [Logger_part.sch]
2019-10-08 working on the pcb v3.5
    [Logger_part.sch, Power_part.sch, _saved_Logger_and_Power.sch]
2019-10-09 now the v3.5 of the PCB: v3, integrated Pololu, with correct names on the PCB
    [Logger_and_Power.kicad_pcb, _saved_Logger_and_Power.sch]
2019-10-25 v3.6 with a bit more on the PCB silk mask
    [Logger_and_Power-B.Cu.gbl, Logger_and_Power-B.Mask.gbs, Logger_and_Power-B.SilkS.gbo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]
2019-10-25 minor stuff
    [Logger_and_Power.kicad_pcb]
2019-12-19 a separate folder with the power controller in working version
2019-12-21 a few small fixes, now also the main ArduinoMega folder should compile with Arduino IDE
2020-02-19 a bit of cleaning old unused folders
    [Logger.csv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]
2020-02-20 attempt to solve a battery voltage readout issue
    [BoardManager.cpp]
